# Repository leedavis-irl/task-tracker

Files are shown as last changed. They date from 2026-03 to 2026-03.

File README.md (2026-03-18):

# Task Tracker

A physical IoT chore tracking system built with ESP32 buttons, a Flask server, and an e-ink display. Buttons are placed at task locations around the house. When a task is completed, pressing the button records it on a central server. A wall-mounted e-ink display shows a live checklist, and a daily summary is sent via Signal.

## How It Works

```
Button press (WiFi) ──HTTP POST──→ Flask server (EC2) ←──HTTP GET── E-ink display (WiFi)
                                        │
                                   9:30 AM daily
                                        │
                                   Signal relay ──→ Signal group
```

1. **Buttons** — Seeed XIAO ESP32-C6 boards with a tact switch, passive buzzer, and LiPo battery. Flashed with ESPHome. On press, sends an HTTP POST to the server with `{"owner": "...", "task": "..."}`.
2. **Server** — Flask app on EC2. Accepts button presses during a configurable morning window (default 6:00–9:30 AM). Tracks task completion per person per day. Resets at 3:00 AM.
3. **Display** — Waveshare 7.5" e-ink (800×480 B/W) on an ESP32 driver board. Polls the server every 60 seconds and renders a two-column checklist.
4. **Signal relay** — Separate Flask endpoint on the same server. At 9:30 AM, the server sends a summary message to a Signal group via signal-cli.

### Buzzer Feedback

Buttons give audio feedback on press:
- **Two short clicks** — task recorded successfully
- **One long click** — task was already completed today
- **Three quick clicks** — outside the active window or error

## Hardware

| Component | Spec | Qty |
|---|---|-----|
| Seeed XIAO ESP32-C6 | WiFi microcontroller, USB-C, LiPo charging | 1 per button |
| 6mm tact switch | Momentary, through-hole | 1 per button |
| Passive buzzer | ~12mm, driven via GPIO toggle | 1 per button |
| 400mAh LiPo | 3.7V, soldered to BAT+/BAT- pads | 1 per button |
| Waveshare 7.5" V2 e-ink | 800×480 B/W, SPI interface | 1 |
| ESP32 driver board | Waveshare universal e-Paper driver, Rev 3 | 1 |
| 3.7V LiPo | Powers display via 5V/GND pins | 1 |

Full bill of materials with sourcing links in `docs/05-bill-of-materials.md`.

### 3D-Printed Enclosures

Button enclosures are designed in OpenSCAD (`3d/button-enclosure.scad`):
- Two-piece snap-fit design (base + lid with integrated button cap)
- Internal layout: battery, tact switch on pillar mount, XIAO, buzzer
- USB-C access on bottom edge for charging
- Buzzer sound holes on side wall

## Server

### Endpoints

| Method | Path | Description |
|---|---|---|
| `GET` | `/health` | Health check — returns `{"status": "ok", "date": "YYYY-MM-DD"}` |
| `POST` | `/press` | Record task completion — body: `{"owner": "...", "task": "..."}` |
| `GET` | `/state` | Current state as flat JSON (for display polling) |

### Response Codes for `/press`

| Status | Meaning |
|---|---|
| `ok` | Task recorded |
| `already_done` | Task was already completed today |
| `outside_window` | Not within the active time window |
| `not_today` | Task not applicable today (day-specific scheduling) |
| `invalid` | Unknown owner or task |

### Task Definitions

Tasks are defined in `server.py` as Python dicts:

```python
DAILY_TASKS = {
    "child_a": ["laundry", "teeth", "plates", "pills"],
    "child_b": ["laundry", "teeth", "plates"],
}
```

Day-specific tasks (e.g., Wednesday-only) are supported via separate dicts.

### Scheduled Jobs

- **3:00 AM Pacific** — Reset all task state for the new day
- **9:30 AM Pacific** — Send Signal summary (e.g., "Child A done | Child B missed: teeth, plates")

## ESPHome Configuration

Devices use a base template pattern:

```
esphome/
├── .base-common.yaml      WiFi, API, OTA (shared by all devices)
├── .base-button.yaml       Button logic, HTTP POST, buzzer, deep sleep
├── .base-display.yaml      SPI, polling, rendering
├── button-*.yaml           Per-device configs (just substitutions + package includes)
├── display-front-door.yaml Full display config with rendering lambda
└── secrets.yaml.template   Template for WiFi/API credentials
```

Each button config is ~10 lines of substitutions that reference the base templates.

### GPIO Assignments (Buttons)

| Pin | Function |
|-----|---|
| GPIO1 (D1) | Tact switch input (active LOW, internal pullup) |
| GPIO2 (D2) | Passive buzzer output (GPIO toggle) |
| GPIO15 | Onboard LED status |
| BAT+/BAT- | LiPo battery pads |

### Known Platform Issues

- **LEDC/rtttl** does not work on ESP32-C6 with esp-idf framework — buzzer uses plain GPIO toggle
- **Deep sleep** disabled due to ESP-IDF 5.1.5 crash on ESP32-C6 wake
- **`verify_ssl: false`** required in HTTP requests even for plain HTTP on esp-idf, or requests fail silently

## Deployment

### Server Setup

```bash
# On EC2
pip install -r server/requirements.txt
cp .env.example .env    # Edit with your values

# Run directly
python server/server.py

# Or via systemd (see server/task-tracker.service)
sudo systemctl enable task-tracker
sudo systemctl start task-tracker
```

### Signal Relay

```bash
# Same EC2 instance, separate service
pip install flask
python ec2/signal_relay.py

# Requires signal-cli installed and registered
```

### Flashing Devices

```bash
# First flash (USB)
esphome run esphome/button-child_a-laundry.yaml

# Subsequent updates (OTA)
esphome run esphome/button-child_a-laundry.yaml --device 192.168.x.x
```

Copy `esphome/secrets.yaml.template` to `esphome/secrets.yaml` and fill in WiFi credentials and server IP before flashing.

## Documentation

Detailed guides in `docs/`:

| Doc | Contents |
|-----|---|
| `01-architecture.md` | System design, data flow, component responsibilities |
| `02-technical-best-practices.md` | ESPHome patterns, server config, e-ink gotchas |
| `03-project-process.md` | Development workflow, testing, deployment procedures |
| `04-task-template.md` | Step-by-step guide for adding new tasks |
| `05-bill-of-materials.md` | Parts list, sourcing, cost breakdown |
| `06-button-design-spec.md` | Enclosure design, mechanical specs |
| `07-deployment.md` | Full EC2 setup and device commissioning |
| `08-button-build-guide.md` | Complete soldering and assembly walkthrough |

## Tech Stack

- **Firmware:** ESPHome (ESP-IDF framework)
- **Microcontrollers:** Seeed XIAO ESP32-C6
- **Display:** Waveshare 7.5" V2 e-ink
- **Server:** Python, Flask, APScheduler
- **Messaging:** signal-cli
- **Enclosures:** OpenSCAD, 3D printed (PLA/PETG)

## License

Private project. Not licensed for redistribution.

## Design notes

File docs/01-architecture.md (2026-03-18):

# Task Tracker System Architecture

## System Overview

A multi-child chore completion tracker using physical IoT buttons, a centralized e-ink status display, and Signal notifications. Designed for Ryker and Logan, expandable to additional children and tasks.

## Core Design Principles

**Physical-first interaction.** Kids press a real button when they complete a task. No apps, no screens to unlock, no accounts to manage. The button is the interface.

**Passive visibility.** The e-ink display at the front door shows current status without power draw, without screens lighting up, without anyone needing to check anything. You see it when you walk past.

**Notification where people look.** Signal was chosen over Slack because more household members check Signal. Technical elegance loses to actual eyeballs.

**One task = one button per child.** Shared tasks (laundry, teeth, plates) get separate buttons with stickers for each kid. No press-counting, no NFC tags, no conventions a 7-year-old has to remember at 7am.

## Hardware Inventory

| Device | Qty | Role | Location |
|---|---|---|---|
| Seeed XIAO ESP32-C6 IoT Button | 2 | Laundry (Ryker + Logan) | Hall laundry chute |
| Seeed XIAO ESP32-C6 IoT Button | 2 | Teeth (Ryker + Logan) | Bathroom |
| Seeed XIAO ESP32-C6 IoT Button | 2 | Plates (Ryker + Logan) | Kitchen sink area |
| Seeed XIAO ESP32-C6 IoT Button | 1 | AM Pills (Ryker only) | Pill case |
| ESP32 dev board + Waveshare 7.5" e-ink | 1 | Status display | Front door |

**Total: 8 devices, ~$110-120**

## Data Flow

```
┌─────────────┐     HTTP POST /press     ┌───────────────────┐
│  IoT Button  │────────────────────────▶│  Flask Server      │
│  (ESP32-C6)  │                         │  (EC2, port 8765)  │
└─────────────┘                          └────────┬──────────┘
                                                   │
                                         ┌─────────┴─────────┐
                                         │                     │
                              GET /state │                     │ 9:30 AM summary
                                         ▼                     ▼
                                  ┌─────────────┐    ┌──────────────┐
                                  │  E-Ink       │    │  Signal Relay │
                                  │  Display     │    │  (EC2 :8766)  │
                                  │  (ESPHome)   │    └──────┬───────┘
                                  └─────────────┘           │
                                                             ▼
                                                    ┌──────────────┐
                                                    │  Signal      │
                                                    │  → Favalon   │
                                                    └──────────────┘
```

### Step-by-step flow for a single button press:

1. **Button press** → ESP32-C6 wakes from deep sleep
2. **ESPHome firmware** → Connects to WiFi, sends HTTP POST to Flask server with `{"owner": "ryker", "task": "teeth"}`
3. **Flask server checks** → Is the active window open (6:00–9:30 AM)? Is this task already done?
4. **Server updates state** → Marks task as done in `state.json`, returns `{"status": "ok"}`
5. **Button buzzer feedback** → Two clicks (success), one long click (already done), three quick clicks (outside window / error)
6. **Display polls** → Every 60 seconds, the e-ink display GETs `/state` from the server
7. **E-ink refreshes** → Redraws two-column checklist with updated checkmarks

### Daily reset flow:

1. **APScheduler job** → Fires at 3:00 AM Pacific
2. **Reset all states** → `state.json` wiped and rebuilt with today's tasks
3. **Display polls** → Picks up fresh state on next 60-second cycle

### 9:30 AM Signal summary:

1. **APScheduler job** → Fires at 9:30 AM Pacific
2. **Build summary** → Checks which tasks each child completed/missed
3. **POST to Signal relay** → Sends message to EC2 Signal relay on port 8766
4. **Signal delivery** → `signal-cli` sends message to Favalon group

## Component Responsibilities

### ESPHome (runs on all 8 devices)

**On buttons:**
- Deep sleep management (wake on button press)
- WiFi connection
- HTTP POST to Flask server with owner/task payload
- Buzzer feedback based on server response (success / already done / outside window)
- Battery voltage reporting (if battery-powered)

**On display:**
- Polls Flask server every 60 seconds via HTTP GET `/state`
- Parses flat JSON response into boolean globals
- Renders two-column layout via display lambda
- Three display modes: outside window, active checklist, all-done celebration

### Flask Server (runs on EC2)

- **Task registry** → Defines all tasks and owners in Python (DAILY_TASKS)
- **State machine** → Tracks completion status per child per task per day in `state.json`
- **Active window** → Only accepts button presses between 6:00–9:30 AM Pacific
- **API endpoints** → `/press` (POST), `/state` (GET), `/health` (GET)
- **Daily reset** → APScheduler clears all states at 3:00 AM Pacific
- **Signal summary** → APScheduler sends one summary at 9:30 AM Pacific via EC2 relay

### Signal Relay (runs on EC2, port 8766)

- Receives summary message from Flask server via HTTP POST
- Sends to Favalon Signal group via `signal-cli`
- Authenticated with shared `RELAY_TOKEN` header

## Server State Model

State is stored in `state.json` on disk. The `/state` endpoint returns a flat JSON object for the display:

```json
{
  "active_window": true,
  "both_done": false,
  "ryker_laundry": false,
  "ryker_teeth": true,
  "ryker_plates": false,
  "ryker_pills": false,
  "ryker_done": false,
  "logan_laundry": false,
  "logan_teeth": false,
  "logan_plates": false,
  "logan_done": false
}
```

## Network Topology

```
Internet
├── EC2 (34.208.73.189)
│   ├── Flask task-tracker server (:8765) — systemd service
│   └── Signal relay (:8766) — signal-cli
│
WiFi Network (Avalon)
├── 7× Seeed XIAO ESP32-C6 buttons (HTTP POST to EC2)
└── 1× ESP32 + e-ink display (HTTP GET from EC2, polls every 60s)
```

All button and display devices communicate with the EC2 server over the internet via HTTP. No local server required. No Home Assistant involvement.

## Expansion Points

**New task:** Add button hardware + ESPHome config + update `DAILY_TASKS` (or `WEDNESDAY_TASKS` for day-specific tasks, currently empty) in `server.py` + update display lambda. Follow the task template in `04-task-template.md`.

**New child:** Add stickered buttons for shared tasks + child-specific buttons. Add new owner to server task definitions. Update display lambda for additional column (display supports up to 3-4 columns at 7.5").

**New notification channel:** Modify `job_morning_summary()` in `server.py` to send via additional channels.

**Schedule changes:** Modify task definitions in `server.py`. The `tasks_for_today()` function makes day-of-week logic trivial to adjust.

## Key Technical Decisions

| Decision | Choice | Rationale |
|---|---|---|
| Server location | AWS EC2 | Always-on, no dependency on local hardware being awake |
| Communication | HTTP (not ESPHome native API) | Buttons POST directly to server; no HA intermediary needed |
| State storage | JSON file on disk | Simple, inspectable, survives restarts |
| Display update | Polling (60s interval) | Simpler than push; e-ink refresh rate makes real-time unnecessary |
| Display tech | E-ink via ESPHome | Always visible unpowered, wall-mounts cleanly |
| Notification | Signal via signal-cli on EC2 | Household actually checks Signal; one summary per day, not per-task |
| Button hardware | Seeed XIAO ESP32-C6 | $10/ea, deep sleep support, ESPHome compatible |
| Config management | ESPHome packages | DRY configs, base templates + per-device overrides |
| Timezone handling | `zoneinfo` Pacific | Server runs on UTC EC2 but all logic uses America/Los_Angeles |

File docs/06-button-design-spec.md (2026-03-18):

# Button Unit Design Specification

Last updated: 2026-02-26

## Design Philosophy

Each button is a standalone wall-mounted unit placed at the location where a task is completed (toothbrush button in the bathroom, dishes button by the sink, etc.). The button press itself should be the reward — a big satisfying palm-slap with an audible confirmation sound that makes boring routines feel like an event.

## Form Factor

### Plunger / Hit Target
- **Diameter**: ~55mm (full palm slap, not finger poke)
- **Shape**: Dome or mushroom cap — convex top surface that invites hitting
- **Travel**: 3-5mm of vertical plunger movement before bottoming out on tact switch
- **Spring-back**: Printed living hinge or captive flexure arms return plunger to resting position after press
- **Surface**: Per-task icon embossed or recessed into top face (see Visual Identity below)
- **Feel**: Solid *thonk* at bottom of travel, immediate snap-back

### Enclosure / Base
- **Shape**: Round or rounded-square base that matches plunger aesthetic
- **Diameter/width**: ~65-70mm (provides rim around plunger)
- **Depth**: ~20-25mm (houses all electronics)
- **Wall mount**: Flat back with Command strip recess or keyhole slot
- **USB-C access**: Port opening on bottom edge for charging/flashing (gravity keeps dust out)
- **Sound**: Open slot or grille for buzzer audio to escape enclosure

### Internal Layout (top to bottom)
```
[Plunger cap — 55mm dome, 3-5mm travel]
        ↓ (presses down on)
[Tact switch — 6×6×5mm, mounted on internal post]
[Buzzer — 12mm passive piezo, mounted to side wall]
[XIAO ESP32-C6 — 21×17.8mm, USB-C port aligned to enclosure opening]
[LiPo battery — 5×20×35mm, below or beside XIAO]
```

## Mechanical Design

### Plunger Mechanism
The plunger is a separate printed piece that moves vertically inside the base. It does NOT click on its own — all tactile feedback comes from the real tact switch at the bottom of travel.

**Travel amplification**: The tact switch has only ~0.25mm of its own travel. The plunger adds 3-5mm of free travel before contact, creating anticipation, then the switch click provides the payoff at the bottom.

**Return mechanism options** (choose during prototyping):
1. **Living hinge arms** (simplest): 2-4 thin PLA/PETG flexure arms connecting plunger to base, pre-loaded to push plunger up. Risk: fatigue over thousands of cycles.
2. **Captive silicone o-ring**: Plunger slides on a central post, compressed o-ring provides return force. More durable, slightly more complex assembly.
3. **Printed leaf springs**: Angled tabs that flex and return. Good middle ground.

**Plunger guides**: Central post or rail system prevents wobble and keeps press straight regardless of where on the dome the kid's hand lands.

### Tact Switch Mounting
- Switch sits on a raised printed post at the bottom of the plunger cavity
- Post height calibrated so switch actuates at the bottom of plunger travel
- Two wires (GPIO + GND) route from switch down to XIAO

### Durability
- Target: 10,000+ presses minimum (roughly 3+ years of daily use)
- PETG preferred over PLA for the plunger and return mechanism (better fatigue resistance)
- PLA acceptable for the base enclosure

## Audio Feedback

### Hardware
- Passive piezo buzzer (~12mm), 2 pins soldered to XIAO GPIO + GND
- Mounted inside enclosure with sound slot/grille in wall for audio escape

### Behavior (configured in ESPHome)
- **On press**: Immediate confirmation tone (short beep or custom sound)
- **Possible enhancements** (implement after MVP):
  - Different tone per task (brush teeth = high sparkle, take out trash = low bonk)
  - Ascending pitch as kid completes more tasks in the morning
  - Victory jingle when all tasks complete
  - Sad trombone if pressed after deadline (just kidding... maybe)

### ESPHome Config Pattern

> **LEDC/rtttl does NOT work** on ESP32-C6 with esp-idf framework (outputs 0V). Use plain GPIO toggle instead — produces audible clicks on the passive buzzer.

```yaml
output:
  - platform: gpio
    pin: GPIO2    # D2 on XIAO ESP32-C6
    id: buzzer_out

# Feedback via GPIO toggle patterns (on/off with delays):
# - Two clicks = success
# - One long click = already done
# - Three quick clicks = outside window / error
```

## Visual Identity

### Per-Task Icons
Each button has an icon embossed or recessed into the plunger face so kids (and adults) can instantly identify the task. Icons designed in OpenSCAD as 2D profiles extruded into the dome surface.

Candidate icons (finalize with kids):
| Task | Icon Idea |
|---|---|
| Brush teeth | Toothbrush or tooth |
| Get dressed | T-shirt or hanger |
| Make bed | Bed or pillow |
| Put away dishes | Plate + fork |
| Dirty clothes in hamper | Laundry basket |
| Backpack ready | Backpack |
| Wednesday: Take out trash | Trash can |
| Wednesday: Extra chore TBD | TBD |

### Color Coding
Since buttons are placed at task locations (not grouped by kid), and both kids do the same tasks, there are two approaches:

**Option A: Shared buttons** — one button per task location, either kid can press it, system tracks who via server logic (e.g., alternating presses, or a "who are you" toggle). Fewer buttons, simpler install.

**Option B: Paired buttons** — two buttons per task location, one per kid, different colors. More buttons (18 instead of 9), but zero ambiguity. Color per kid (e.g., Ryker = blue, Logan = green).

**Recommendation**: Start with Option B (paired). It's more hardware but eliminates all "whose turn" confusion. 18 buttons = 18 XIAO boards... except we only have 9. So either:
- Option A with shared buttons (9 boards, need identification mechanism)
- Option B with 9 boards covering one kid, expand later
- Revisit architecture

> **DECISION NEEDED**: Shared vs paired buttons. This affects board count and enclosure design.

## Mounting

### Location Strategy
Buttons mounted as close to task completion point as possible:
- Bathroom wall (brush teeth)
- Near laundry hamper/chute (dirty clothes)
- Near kitchen sink (dishes)
- Bedroom wall (make bed, get dressed)
- Near front door (backpack)
- Near trash/recycling (Wednesday tasks)

### Attachment
- **Primary**: Command strips (3M damage-free, removable, re-positionable)
- **Backup**: Small screws into wall if Command strips don't hold
- Flat back surface with recessed area for Command strip adhesive
- Button should be at kid-reachable height (~36-42" from floor depending on kid)

## Charging

- USB-C port accessible on bottom edge of enclosure
- Plug in any USB-C cable to charge (XIAO onboard charger handles LiPo)
- Charging frequency: estimated every few months (15µA deep sleep + brief wake per press)
- No indicator LED needed — XIAO has onboard charge LED visible through enclosure gap or translucent section

## GPIO Allocation (XIAO ESP32-C6)

| GPIO | XIAO Pin | Function |
|---|---|---|
| GPIO1 | D1 | Tact switch input (internal pull-up, active LOW) |
| GPIO2 | D2 | Passive buzzer output (plain GPIO toggle) |
| GPIO15 | (onboard) | Status LED (active low) |
| BAT+ | pad near D5 | LiPo positive |
| BAT- | pad near D8 | LiPo negative |
| USB-C | — | Charging + flashing |

> **Pin mapping**: D0=GPIO0, D1=GPIO1, D2=GPIO2, D3=GPIO21, D4=GPIO22, D5=GPIO23. GPIO3 is RF switch power (board-internal, do NOT use).

## Prototype Plan

1. **Mechanical prototype first**: Print plunger + base without electronics. Test travel feel, spring-back, palm-slap satisfaction.
2. **Electronics test**: Solder one complete unit (XIAO + battery + switch + buzzer). Confirm ESPHome config, deep sleep wake, buzzer tones.
3. **Integrated prototype**: Combine mechanical + electronics in one unit. Wall-mount test.
4. **Iterate**: Refine based on kid feedback before building all 9.

## Open Questions

- [ ] Shared vs paired buttons (see Visual Identity section)
- [ ] Specific plunger return mechanism (living hinge vs o-ring vs leaf spring) — decide during prototyping
- [ ] Icon designs — involve kids in choosing
- [x] ~~Exact GPIO pin assignments for switch and buzzer~~ — resolved: D1/GPIO1 (switch), D2/GPIO2 (buzzer)
- [ ] PETG color filament availability for kid-specific colors

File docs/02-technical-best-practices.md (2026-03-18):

# Technical Best Practices

## ESPHome Configuration

### File Organization

Use ESPHome's packages system to keep configs DRY. The structure:

```
esphome/
├── secrets.yaml                    # WiFi, API keys, server IP
├── .base-common.yaml               # WiFi, API, OTA, logger (all devices)
├── .base-button.yaml               # Button-specific: HTTP POST, buzzer feedback
├── .base-display.yaml              # Display-specific: SPI, fonts, polling base
├── button-ryker-laundry.yaml       # Per-device config
├── button-ryker-teeth.yaml
├── button-logan-laundry.yaml
├── ...
└── display-front-door.yaml
```

Dot-prefix on base files (`.base-*`) keeps them grouped at top of directory listings and signals "don't flash this directly."

### Base Common Config (.base-common.yaml)

Every device inherits this. Contains:

```yaml
wifi:
  ssid: !secret wifi_ssid
  password: !secret wifi_password
  ap:
    ssid: "${device_name} Fallback"
    password: "fallback1234"

api:
  encryption:
    key: !secret api_encryption_key

ota:
  - platform: esphome
    password: !secret ota_password

logger:
  level: INFO
```

### Per-Device Config Pattern

Each device YAML is minimal — just substitutions and package includes:

```yaml
substitutions:
  device_name: button-ryker-laundry
  owner: ryker
  task: laundry
  pi_ip: !secret pi_ip

packages:
  common: !include .base-common.yaml
  button: !include .base-button.yaml
```

This means adding a new button = copying a 10-line file and changing 4 substitution values.

### Substitutions as the Interface

Substitutions are the contract between base configs and per-device configs:

| Substitution | Used In | Example |
|---|---|---|
| `${device_name}` | Common (hostname, AP name) | `button-ryker-laundry` |
| `${owner}` | Button base (HTTP POST body) | `ryker` |
| `${task}` | Button base (HTTP POST body) | `laundry` |
| `${pi_ip}` | Button/display base (server URL) | `34.208.73.189` |

### Naming Conventions (ESPHome)

**Device names:** `{type}-{owner}-{task}` using hyphens (RFC1912 compliant)
- `button-ryker-laundry`
- `button-logan-teeth`
- `display-front-door`

### Deep Sleep for Buttons

Buttons spend 99.9% of their time asleep. Config pattern:

```yaml
deep_sleep:
  id: deep_sleep_control
  run_duration: 10s        # Max awake time per press
  sleep_duration: 0s       # Sleep indefinitely (wake on pin)
  wakeup_pin:
    number: GPIO1
    mode: INPUT_PULLUP
    inverted: true
```

Key rules:
- **10 second max awake time** — connect WiFi, send HTTP POST, get response, sleep
- **No periodic wake** — only wake on physical button press
- **Fallback** — if WiFi fails within 10s, sleep anyway (don't drain battery)

> **Note:** Deep sleep is currently disabled due to ESP-IDF 5.1.5 sleep crash on ESP32-C6. Will be re-enabled in a future firmware update.

### Buzzer Feedback Pattern

```yaml
output:
  - platform: gpio
    pin: GPIO2    # D2 on XIAO ESP32-C6
    id: buzzer_out

# Feedback via GPIO toggle patterns (on/off with delays):
# - Two clicks = success ("ok" from server)
# - One long click = already done today
# - Three quick clicks = outside window / error
```

> **LEDC/rtttl does NOT work** on ESP32-C6 with esp-idf framework (outputs 0V). Use plain GPIO toggle instead.

### HTTP Request Configuration

Both buttons and display use the `http_request` component. Critical setting:

```yaml
http_request:
  useragent: "ESPHome Task Button"
  timeout: 5s
  verify_ssl: false    # Required — without this, HTTP requests fail silently on esp-idf
```

The `verify_ssl: false` is needed even for plain HTTP on the esp-idf framework. Without it, requests will silently fail with no error in logs.

### E-Ink Display Best Practices

**Pin configuration for Waveshare 7.5" V2 with ESP32 driver board:**

```yaml
spi:
  clk_pin: GPIO13
  mosi_pin: GPIO14

display:
  - platform: waveshare_epaper
    id: eink_display
    model: 7.50inV2
    cs_pin: GPIO15
    dc_pin: GPIO27
    busy_pin:
      number: GPIO25
      inverted: true      # REQUIRED for 7.50in V2 — prevents display damage
    reset_pin: GPIO26
    update_interval: never  # Only update after receiving new state from server
    lambda: |-
      // Display rendering code here
```

**Critical rules:**
- `busy_pin: inverted: true` is MANDATORY for 7.50in V2 models. Omitting this can damage the display.
- Set `update_interval: never` — the poll script calls `epaper.update()` after receiving new state
- Keep fonts to 2-3 sizes max to conserve flash memory
- Use ASCII glyphs only ([X], ( ), -) — Unicode markers (✓, ○, ⚠) require special font files
- Restrict glyph sets to only the characters actually used to minimize flash usage

### Secrets Management

Single `secrets.yaml` in the ESPHome config directory:

```yaml
wifi_ssid: "YourNetworkName"
wifi_password: "YourWiFiPassword"
api_encryption_key: "base64-encoded-32-byte-key"
ota_password: "OtaUpdatePassword"
pi_ip: "34.208.73.189"
relay_token: "your_shared_secret"
```

**Rules:**
- Never commit secrets.yaml to version control
- Generate API encryption key with: `python3 -c "import secrets, base64; print(base64.b64encode(secrets.token_bytes(32)).decode())"`
- All devices share the same API key
- OTA password is separate from API key
- `pi_ip` is the EC2 server address (misnamed for historical reasons — it's not a Pi)

## Server Configuration

### Task Definitions

Tasks are defined in `server.py` as Python dicts:

```python
DAILY_TASKS = {
    "ryker": ["laundry", "teeth", "plates", "pills"],
    "logan": ["laundry", "teeth", "plates"],
}

WEDNESDAY_TASKS = {
    "ryker": [],
    "logan": [],
}
```

To add a new task, add it to the appropriate dict and restart the server.

### Timezone Handling

The server runs on EC2 (UTC system clock) but all time-dependent logic uses Pacific time:

```python
from zoneinfo import ZoneInfo
PACIFIC = ZoneInfo("America/Los_Angeles")

# All datetime.now() calls use:
now = datetime.now(PACIFIC)
```

This applies to: active window check, weekday calculation for day-specific tasks, and daily reset scheduling (APScheduler uses `timezone="America/Los_Angeles"`).

### Signal Integration

Signal messages are sent via a relay endpoint on EC2 (port 8766) using `signal-cli`. The task tracker server sends one summary per day at 9:30 AM Pacific:

```
Ryker done | Logan missed: teeth, plates
```

The relay authenticates via `X-Relay-Token` header (shared secret between task tracker server and signal relay).

## Version Control

### What to track in Git

```
task-tracker/
├── esphome/
│   ├── .base-common.yaml
│   ├── .base-button.yaml
│   ├── .base-display.yaml
│   ├── button-*.yaml           (one per physical button)
│   └── display-front-door.yaml
├── server/
│   ├── server.py
│   ├── requirements.txt
│   └── task-tracker.service
├── ec2/
│   └── signal_relay.py
├── docs/
│   └── *.md
└── .gitignore
```

### .gitignore

```
secrets.yaml
.esphome/
buzzer-test.yaml
*-flash.yaml
*.pyc
```

### Commit Conventions

- `feat(button): add Ryker vitamins daily button`
- `fix(display): correct column alignment for two-child layout`
- `docs: update task template with schedule configuration notes`
- `refactor(esphome): extract LED feedback to shared package`

## Error Handling

### Button fails to connect to WiFi
ESPHome's 10-second run_duration ensures the button goes back to sleep. Battery is preserved. Task simply doesn't register — kid can press again.

### Display stops updating
E-ink retains last image. Stale data is visible and obvious (yesterday's tasks still shown). Check EC2 server is running: `systemctl status task-tracker`.

### Server goes down
Buttons will get HTTP errors and play the three-click error pattern. Display retains last rendered image. Restart with `sudo systemctl restart task-tracker` on EC2.

### Signal relay fails
Summary message fails silently. Tasks still register on the server and display. Signal is a nice-to-have, not a critical path.

### Duplicate button press
Server checks if task is already done and returns `"already_done"`. Button plays one long click. State is not modified.

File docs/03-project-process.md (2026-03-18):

# Project Process

## Development Phases

### Phase 1: Infrastructure (do once)

1. **Set up ESPHome environment** on local machine (`pip install esphome`)
2. **Create base YAML files** (`.base-common.yaml`, `.base-button.yaml`, `.base-display.yaml`)
3. **Create `secrets.yaml`** with WiFi credentials, API keys, server IP
4. **Deploy Flask server** to EC2 with systemd service
5. **Deploy Signal relay** to EC2 with signal-cli
6. **Set up Git repo** with initial commit of all config files

### Phase 2: First Button (prove the pattern)

Build ONE complete task end-to-end before replicating. Suggested: **Ryker teeth button**.

1. Flash ESPHome to one Seeed XIAO ESP32-C6 via USB
2. Verify WiFi connects and button boots cleanly (two clicks)
3. Press button, verify HTTP POST reaches EC2 server
4. Verify server records the task (`/state` shows `true`)
5. Verify display picks up the change on next poll
6. Test daily reset clears state
7. Test duplicate press protection (one long click)

**Do not proceed to Phase 3 until this single button works completely.**

### Phase 3: Fleet Deployment (replicate the pattern)

For each remaining button:
1. Copy per-device YAML, change substitutions
2. Flash ESPHome firmware via USB
3. Verify WiFi connection and boot feedback
4. Test button → server → display chain
5. Apply sticker, mount with Command strip

### Phase 4: Polish

1. Finalize display layout (both columns, all tasks)
2. Test full day cycle: morning tasks → display updates → 9:30 AM summary → reset overnight
3. Verify day-specific tasks (if any) appear/hide correctly
4. Document any deviations from best practices

## Development Workflow (per-session)

### Before starting work

1. Pull latest from Git
2. Verify EC2 server is running: `curl http://34.208.73.189:8765/health`
3. Check server logs if needed: `ssh ubuntu@34.208.73.189 "sudo journalctl -u task-tracker --since '1 hour ago'"`

### Making changes

1. **ESPHome changes:** Edit YAML → compile (`esphome compile`) → flash OTA or USB (`esphome upload`)
2. **Server changes:** Edit `server.py` → deploy to EC2 → restart service (`sudo systemctl restart task-tracker`)
3. **Task definition changes:** Edit `DAILY_TASKS` (or `WEDNESDAY_TASKS` for day-specific tasks) in `server.py` → restart server → update display lambda if new task row needed

### After making changes

1. Test the specific change manually (press button, check state, check display)
2. Commit to Git with descriptive message
3. Note any issues in project log

## Testing Checklist

### Per-button commissioning test

Run this for every new button before mounting:

- [ ] ESPHome firmware compiles without errors
- [ ] Device connects to WiFi (check serial logs)
- [ ] Boot feedback: two clicks heard
- [ ] Button press: HTTP POST reaches EC2 server (check server logs)
- [ ] Server responds `"ok"` and task state updates
- [ ] Display shows updated state on next poll
- [ ] Second button press returns `"already_done"` (one long click)
- [ ] Device returns to deep sleep after press (when deep sleep is re-enabled)

### System-level tests (run after fleet changes)

- [ ] Daily reset clears all states at 3 AM (test by temporarily changing reset time)
- [ ] Display shows correct day's tasks (including any day-specific tasks if configured)
- [ ] 9:30 AM Signal summary sends correctly
- [ ] Display handles all tasks checked off (celebration screen)
- [ ] Display handles zero tasks checked off (morning state)

### Edge case tests

- [ ] Button press while WiFi is down → button sleeps, no crash
- [ ] Button press while server is down → three clicks (error), no crash
- [ ] Multiple buttons pressed simultaneously → all register correctly
- [ ] Press day-specific task button on wrong day → server returns `"not_today"`, three clicks
- [ ] Press outside 6–9:30 AM window → server returns `"outside_window"`, three clicks

## Deployment Steps (mounting a button)

1. **Label the button** with kid's sticker and task icon/text
2. **Test one more time** in the mounting location (WiFi signal check)
3. **Clean surface** with isopropyl alcohol
4. **Apply Command strip** to button back
5. **Press to wall** for 30 seconds
6. **Verify press from mounted position** — check EC2 server logs to confirm POST received
7. **Take a photo** of mounted button for documentation
8. **Update inventory** in architecture doc if placement changed

## Rollback Procedures

### Bad ESPHome firmware flash

ESPHome devices have fallback AP mode. If a bad flash prevents WiFi connection:
1. Look for `{device_name} Fallback` WiFi network
2. Connect and navigate to `192.168.4.1`
3. Flash corrected firmware via web interface

### Server issues

```bash
# SSH into EC2
ssh -i ~/.ssh/the-pem-key.pem ubuntu@34.208.73.189

# Check status
sudo systemctl status task-tracker

# View logs
sudo journalctl -u task-tracker -f

# Restart
sudo systemctl restart task-tracker
```

### Signal relay issues

```bash
# On EC2:
sudo systemctl status signal-relay
sudo systemctl restart signal-relay
```

## Monitoring

### Daily glance checks

- Server health: `curl http://34.208.73.189:8765/health`
- Current state: `curl http://34.208.73.189:8765/state | python3 -m json.tool`
- Signal group: confirm 9:30 AM summary arrived

### Weekly maintenance

- Check button batteries if not USB-powered
- Review EC2 server logs for recurring warnings
- Verify display is rendering cleanly (e-ink ghosting check)
- Git commit any uncommitted changes

### Monthly review

- Are kids actually using it? Talk to them.
- Any tasks need adding/removing/changing?
- Any buttons fallen off walls? (Command strip refresh)
- Update ESPHome if updates available

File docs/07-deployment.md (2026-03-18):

# Task Tracker — Deployment Guide

End-to-end setup for the Avalon household task tracker:
7 ESPHome buttons + 1 e-ink display + EC2 server + EC2 Signal relay.

---

## Overview

```
[Button press]
     │  HTTP POST /press
     ▼
[EC2 Server :8765]  ──── GET /state ────▶  [E-ink Display]
     │
     │  9:30 AM summary only
     ▼
[EC2 :8766 /send-signal]
     │
     ▼
[Signal → Favalon group]
```

**Signal behavior:** One message per day, sent at 9:30 AM Pacific.
Format: `Ryker done | Logan missed: teeth, plates`
No real-time notifications when tasks are completed.

---

## Prerequisites

- AWS EC2 instance (currently at 34.208.73.189) with ports 8765 and 8766 open
- SSH key: `~/.ssh/the-pem-key.pem`
- signal-cli configured on EC2 for +17074748930
- 7× Seeed XIAO ESP32-C6 boards
- 1× Waveshare 7.5" V2 e-ink display + Waveshare ESP32 driver board
- A machine with ESPHome installed (`pip install esphome`)

---

## Part 1 — EC2 Signal Relay

Do this first so you can test it independently.

### 1.1 SSH into EC2

```bash
ssh -i ~/.ssh/the-pem-key.pem ubuntu@34.208.73.189
```

### 1.2 Copy signal_relay.py

```bash
scp -i ~/.ssh/the-pem-key.pem \
  task-tracker/ec2/signal_relay.py \
  ubuntu@34.208.73.189:~/signal_relay.py
```

### 1.3 Install Flask (if not already present)

```bash
pip3 install flask
```

### 1.4 Choose a relay token

Pick any strong random string. You'll use the same value in two places:
- `RELAY_TOKEN` env var on EC2 (signal relay)
- `RELAY_TOKEN` env var in the task-tracker systemd service

```bash
# Generate one:
openssl rand -hex 24
```

### 1.5 Run standalone (test first)

```bash
RELAY_TOKEN=your_token_here python3 ~/signal_relay.py &
```

### 1.6 Open firewall port 8766

In AWS Console → EC2 → Security Groups, add inbound rule:
- Type: Custom TCP
- Port: 8766
- Source: 0.0.0.0/0 (or restrict to your home IP)

### 1.7 Test it

```bash
curl -X POST http://34.208.73.189:8766/send-signal \
  -H "Content-Type: application/json" \
  -H "X-Relay-Token: your_token_here" \
  -d '{"message": "Test from task tracker"}'
# Expected: {"status": "sent"}
```

Check that the message appeared in the Favalon Signal group.

### 1.8 Make it persistent (systemd)

```bash
sudo cat > /etc/systemd/system/signal-relay.service << 'EOF'
[Unit]
Description=Signal Relay for Task Tracker
After=network.target

[Service]
Type=simple
User=ubuntu
Environment="RELAY_TOKEN=REPLACE_WITH_YOUR_TOKEN"
ExecStart=/usr/bin/python3 /home/ubuntu/signal_relay.py
Restart=always
RestartSec=5

[Install]
WantedBy=multi-user.target
EOF

sudo systemctl daemon-reload
sudo systemctl enable signal-relay
sudo systemctl start signal-relay
sudo systemctl status signal-relay
```

---

## Part 2 — EC2 Task Tracker Server

### 2.1 Copy server files to EC2

```bash
scp -i ~/.ssh/the-pem-key.pem \
  task-tracker/server/server.py \
  task-tracker/server/requirements.txt \
  ubuntu@34.208.73.189:~/task-tracker/
```

### 2.2 Set up Python virtualenv

```bash
ssh -i ~/.ssh/the-pem-key.pem ubuntu@34.208.73.189

cd ~/task-tracker
python3 -m venv venv
source venv/bin/activate
pip install -r requirements.txt
deactivate
```

### 2.3 Configure the systemd service

```bash
sudo cat > /etc/systemd/system/task-tracker.service << 'EOF'
[Unit]
Description=Avalon Task Tracker Server
After=network-online.target
Wants=network-online.target

[Service]
Type=simple
User=ubuntu
WorkingDirectory=/home/ubuntu/task-tracker
Environment="STATE_FILE=/home/ubuntu/task-tracker/state.json"
Environment="EC2_RELAY_URL=http://127.0.0.1:8766/send-signal"
Environment="RELAY_TOKEN=REPLACE_WITH_YOUR_TOKEN"
ExecStart=/home/ubuntu/task-tracker/venv/bin/python server.py
Restart=always
RestartSec=5
StandardOutput=journal
StandardError=journal
SyslogIdentifier=task-tracker

[Install]
WantedBy=multi-user.target
EOF

sudo systemctl daemon-reload
sudo systemctl enable task-tracker
sudo systemctl start task-tracker
sudo systemctl status task-tracker
```

Note: `EC2_RELAY_URL` uses `127.0.0.1` since both services run on the same EC2 instance.

### 2.4 Verify the server

```bash
# From any device:
curl http://34.208.73.189:8765/health
# Expected: {"status": "ok", "date": "2026-03-11"}

curl http://34.208.73.189:8765/state
# Expected: JSON with all tasks false, active_window true/false depending on time

# Simulate a button press:
curl -X POST http://34.208.73.189:8765/press \
  -H "Content-Type: application/json" \
  -d '{"owner": "ryker", "task": "laundry"}'
# Expected: {"status": "ok"} or {"status": "outside_window"}
```

### 2.5 Watch logs

```bash
sudo journalctl -u task-tracker -f
```

---

## Part 3 — ESPHome Secrets

### 3.1 Fill in secrets.yaml

```bash
cd task-tracker/esphome
cp secrets.yaml.template secrets.yaml
```

Edit `secrets.yaml`:

```yaml
wifi_ssid: "Avalon"
wifi_password: "YourWiFiPassword"
api_encryption_key: "$(openssl rand -base64 32)"
ota_password: "choose_something"
pi_ip: "34.208.73.189"
relay_token: "your_token"
```

**Never commit secrets.yaml.** It is in `.gitignore`.

---

## Part 4 — Flash the Buttons (9× Seeed XIAO ESP32-C6)

Flash each button one at a time. Label each board before flashing.

### 4.1 Install ESPHome (if not already)

```bash
pip install esphome
```

### 4.2 Flash each button

Connect the XIAO ESP32-C6 via USB-C. Then for each button yaml:

```bash
cd task-tracker/esphome

# First flash (wired):
esphome run button-ryker-laundry.yaml --device /dev/cu.usbmodem*

# Subsequent flashes (OTA, once on WiFi):
esphome upload button-ryker-laundry.yaml --device button-ryker-laundry.local
```

Repeat for all 7 buttons:
- button-ryker-laundry
- button-ryker-teeth
- button-ryker-plates
- button-ryker-pills
- button-logan-laundry
- button-logan-teeth
- button-logan-plates

### 4.3 Test each button

After flashing, press the physical button. Watch the EC2 logs:

```bash
ssh -i ~/.ssh/the-pem-key.pem ubuntu@34.208.73.189 \
  "sudo journalctl -u task-tracker -f"
```

You should see: `Recorded: ryker / laundry`

The button should play two clicks on success.

**Outside 6–9:30 AM window:** The server returns `outside_window` and the
button plays three quick clicks. This is expected.

---

## Part 5 — Flash the Display (Waveshare 7.5" V2)

### 5.1 Verify pi_ip in secrets.yaml

The display config references `!secret pi_ip` which should be `34.208.73.189`.

### 5.2 Flash the display board

The Waveshare ESP32 driver board connects via USB.

```bash
cd task-tracker/esphome
esphome run display-front-door.yaml
```

For OTA updates:
```bash
esphome upload display-front-door.yaml --device display-front-door.local
```

### 5.3 Verify display behavior

**During active window (6:00–9:30 AM):**
- Left column: Ryker's tasks with ( ) (pending) or [X] (done)
- Right column: Logan's tasks

**Outside active window:**
- Shows "Good morning! / Tasks open 6:00 – 9:30 AM"

**Both kids done:**
- Shows "All done! / Ryker [X]  |  Logan [X]"

The display polls the server every 60 seconds.

---

## Part 6 — Signal Message Verification

The system sends **one Signal message per day**, at 9:30 AM Pacific.

### Format

```
Ryker done | Logan done
Ryker done | Logan missed: teeth, plates
Ryker missed: pills | Logan missed: teeth, plates
```

### Force a test

```bash
# Send a test message directly through the relay:
curl -X POST http://34.208.73.189:8766/send-signal \
  -H "Content-Type: application/json" \
  -H "X-Relay-Token: your_token_here" \
  -d '{"message": "Ryker done | Logan missed: teeth, plates"}'
```

---

## Part 7 — Daily Reset Verification

The 3:00 AM reset wipes all task state. To verify without waiting:

```bash
# Check current state
curl http://34.208.73.189:8765/state | python3 -m json.tool

# Manually wipe state (on EC2):
ssh -i ~/.ssh/the-pem-key.pem ubuntu@34.208.73.189 \
  "echo '{}' > ~/task-tracker/state.json && sudo systemctl restart task-tracker"

# State should reload fresh for today
curl http://34.208.73.189:8765/state | python3 -m json.tool
```

---

## Troubleshooting

| Symptom | Check |
|---|---|
| Button plays three clicks always | Is it outside 6–9:30 AM window? Check EC2 server time |
| Button plays nothing | Check WiFi — button may not be reaching server |
| Display shows stale data | Check EC2 server is running: `curl http://34.208.73.189:8765/health` |
| Display shows "Good morning!" during active hours | Server may be down or display can't reach EC2 |
| No Signal message at 9:30 | Check server logs for relay errors; verify signal relay is running |
| Signal relay returns 401 | Token mismatch — verify same RELAY_TOKEN on server and relay |
| signal-cli not found | Update SIGNAL_CLI path in signal_relay.py or env var |
| State resets unexpectedly | Corrupt state.json — server auto-recovers on restart |
| HTTP requests from buttons fail silently | Ensure `verify_ssl: false` is in `.base-button.yaml` http_request config |

---

## Infrastructure Reference

```
EC2 Instance: 34.208.73.189
  SSH: ssh -i ~/.ssh/the-pem-key.pem ubuntu@34.208.73.189
  Services:
    task-tracker (port 8765) — Flask server, systemd
    signal-relay (port 8766) — signal-cli relay, systemd
  Security group: ports 22, 8765, 8766 open

WiFi: Avalon (home network)
  Buttons and display connect via WiFi, POST/GET to EC2 over internet
```

## File Reference

```
task-tracker/
├── esphome/
│   ├── secrets.yaml.template   ← copy → secrets.yaml, fill in values
│   ├── .base-common.yaml       ← WiFi/API/OTA shared config
│   ├── .base-button.yaml       ← button behavior (HTTP POST, buzzer feedback)
│   ├── .base-display.yaml      ← display SPI/fonts/polling base
│   ├── button-*.yaml           ← one per physical button (7 total)
│   └── display-front-door.yaml ← e-ink display config + render lambda
├── server/
│   ├── server.py               ← Flask server (runs on EC2)
│   ├── requirements.txt        ← pip deps
│   └── task-tracker.service    ← systemd unit (reference — actual is on EC2)
├── ec2/
│   └── signal_relay.py         ← Signal relay Flask app
└── docs/
    └── *.md                    ← documentation
```

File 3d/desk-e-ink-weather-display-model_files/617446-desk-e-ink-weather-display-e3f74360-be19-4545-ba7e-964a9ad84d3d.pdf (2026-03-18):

## Desk e-ink weather

## display

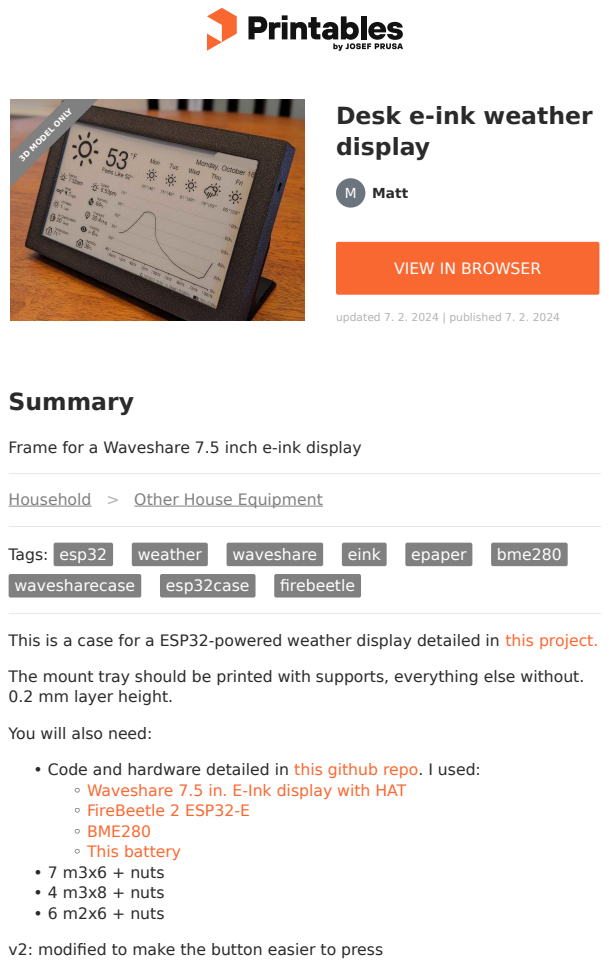
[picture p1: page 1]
Summary; Household; Other House Equipment; Tags: esp32; weather; waveshare; eink; epaper; bme280; wavesharecase; esp32case; firebeetle; Waveshare 7.5 in. E-Ink display with HAT; FireBeetle 2 ESP32-E; BME280; This battery; 7 m3x6 + nuts; 4 m3x8 + nuts; 6 m2x6 + nuts; Matt; updated 7. 2. 2024 | published 7. 2. 2024; 3D MODEL ONLY

VIEW IN BROWSER (https://printables.com/model/617446-desk-e-ink-weather-display)

Frame for a Waveshare 7.5 inch e-ink display

This is a case for a ESP32-powered weather display detailed in this project. (https://github.com/lmarzen/esp32-weather-epd/)

The mount tray should be printed with supports, everything else without.
0.2 mm layer height.

You will also need:

Code and hardware detailed in this github repo. (https://github.com/lmarzen/esp32-weather-epd/) I used:

v2: modified to make the button easier to press

# Model files

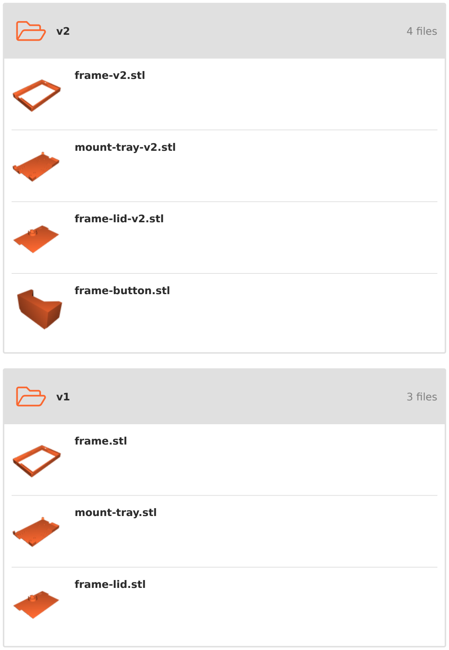
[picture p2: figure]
4 files; 3 files; frame-v2.stl; mount-tray-v2.stl; frame-lid-v2.stl; frame-button.stl; frame.stl; mount-tray.stl; frame-lid.stl

## License

This work is licensed under a

Creative Commons (4.0 International License) (http://creativecommons.org/licenses/by-nc-sa/4.0/)

battery-clip.stl

wire-clip.stl

stand-right-60.stl

stand-left-60.stl

stand-right-45.stl

stand-left-45.stl

stand-right-75.stl

stand-left-75.stl

Attribution—Noncommercial—Share Alike (http://creativecommons.org/licenses/by-nc-sa/4.0/)

✖ | Sharing without ATTRIBUTION
✔ | Remix Culture allowed
✖ | Commercial Use
✖ | Free Cultural Works
✖ | Meets Open Definition

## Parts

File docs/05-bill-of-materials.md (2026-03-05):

# Bill of Materials

Last updated: 2026-02-26

## On Hand

- 9× Seeed XIAO ESP32-C6 boards
- 1× Waveshare 7.5" e-ink raw panel (800×480, B/W)
- 1× Waveshare e-Paper ESP32 Driver Board ([B07M5CNP3B](https://www.amazon.com/dp/B07M5CNP3B))
- Bambu Lab 3D printers + filament (PLA/PETG)
- Soldering iron + solder
- USB-C cables for flashing/charging
- Command strips for wall mounting

## To Purchase

### 1. Passive Piezo Buzzers
- **Product**: Cylewet 5V 2-pin passive electromagnetic buzzer, 10-pack
- **Quantity**: 1 pack (need 9, rest are spares)
- **Price**: ~$6
- **Specs**: 2-pin, passive, ~12mm diameter, 3-5V operating range
- **Link**: Search "Cylewet 10pcs 5V passive buzzer electromagnetic beeper" on Amazon
- **Notes**: Passive (not active) — allows PWM tone control via ESPHome LEDC output. Solder one pin to GPIO, one to GND. Works at 3.3V. Enables per-task sounds, victory jingles, ascending scales as tasks complete.

### 2. LiPo Batteries — Button Units
- **Product**: Liter 3.7V 400mAh 502035 LiPo
- **Quantity**: 10 (9 units + 1 spare)
- **Price**: ~$8 each, ~$80 total
- **Dimensions**: 5mm × 20mm × 35mm
- **Connector**: JST PH 2.0mm (cut off, solder bare wires to XIAO BAT+/BAT- pads)
- **Link**: Search "Liter 502035 400mAh" on Amazon
- **Notes**: XIAO BAT- pad near D8 silkscreen, BAT+ near D5. Built-in USB-C charging on XIAO handles recharging.

### 3. LiPo Battery — E-ink Display
- **Product**: Liter 3.7V 3000mAh 105050 LiPo
- **Quantity**: 1
- **Price**: ~$10
- **Dimensions**: 9.9mm × 50mm × 48mm (fits behind 170×111mm panel)
- **Connector**: JST PH 2.0mm (cut off, solder to TP4056 battery pads)
- **Link**: [B09FL7QD88](https://www.amazon.com/dp/B09FL7QD88)
- **Notes**: Verify polarity with multimeter before connecting. Some units ship with red/black swapped on JST.

### 4. TP4056 USB-C LiPo Charger Modules
- **Product**: HiLetgo TP4056 Type-C USB 5V 1A 18650 Lithium Battery Charger Module
- **Quantity**: 3-pack
- **Price**: ~$6
- **Link**: Search "HiLetgo TP4056 Type-C 3pcs" on Amazon
- **Notes**: Get version WITH protection (DW01 chip) for overdischarge protection. Wiring: USB-C → TP4056 → battery → Waveshare 5V/GND pins. Only needed for e-ink display (XIAO boards have built-in charging).

### 5. Tactile Pushbutton Switches
- **Product**: DAOKI 6×6×5mm tactile switches, 100-pack
- **Quantity**: 1 pack (need 9, rest are spares)
- **Price**: ~$6
- **Specs**: Through-hole, 4-pin, momentary, DC12V 50mA rated
- **Link**: [B01CGMP9GY](https://www.amazon.com/dp/B01CGMP9GY)
- **Notes**: Solder two wires per switch (GPIO + GND). Mount under 3D-printed plunger cap for kid-friendly feel. 5mm button height provides good tactile feedback.

### 6. Hookup Wire
- **Product**: BNTECHGO 22 AWG Silicone Wire (red + black, 10ft each)
- **Quantity**: 1 kit
- **Price**: ~$6
- **Specs**: 22 gauge stranded tinned copper, 60 strands × 0.08mm, 1.7mm OD, silicone insulation
- **Link**: Search "BNTECHGO 22 AWG silicone red black" on Amazon
- **Notes**: Silicone insulation rated -60°C to +200°C, won't melt during soldering. Use for switch-to-GPIO and battery-to-pad connections.

### 7. Heat Shrink Tubing
- **Product**: Heat shrink tubing assortment kit (580pcs, 11 sizes)
- **Quantity**: 1 kit
- **Price**: ~$7
- **Primary sizes needed**:
  - 1/12" (2.1mm): for battery wire solder joints
  - 1/8" (3.2mm): for 22 AWG hookup wire joints
- **Link**: Search "580pcs heat shrink tubing assortment" on Amazon
- **Notes**: Critical for LiPo safety — insulate all battery solder connections.

## Cost Summary

| Category | Est. Cost |
|---|---|
| Passive piezo buzzers (10-pack) | $6 |
| Button unit batteries (10×) | $80 |
| E-ink display battery (1×) | $10 |
| TP4056 charger modules (3-pack) | $6 |
| Tactile switches (100-pack) | $6 |
| Hookup wire | $6 |
| Heat shrink tubing | $7 |
| **Total** | **~$121** |

## Power Architecture

### Button Units (×9)
```
[3.7V 400mAh LiPo] → solder to XIAO BAT+/BAT- pads
                       ↕ (USB-C plugged in = charges battery via XIAO onboard charger)
[XIAO ESP32-C6] → deep sleep 15µA → months between charges
```

### E-ink Display (×1)
```
[USB-C] → [TP4056 w/ protection] → [3.7V 3000mAh LiPo] → [Waveshare 5V/GND pins]
           (charging)                (storage)               (power)
```

## 3D-Printed Components (designed in OpenSCAD, printed on Bambu Lab)

- **Button unit enclosure**: Houses XIAO + battery + tact switch + buzzer. USB-C port access for charging/flashing. Wall-mountable. Color-coded or labeled per kid.
- **Button plunger cap**: Large kid-friendly dome/palm-slap target (~55mm diameter) with 3-5mm printed travel and spring-back mechanism. Presses down on 6×6mm tact switch at bottom of travel.
- **E-ink display frame**: Mounts 7.5" panel + driver board + battery + TP4056. Wall-mountable at front door.

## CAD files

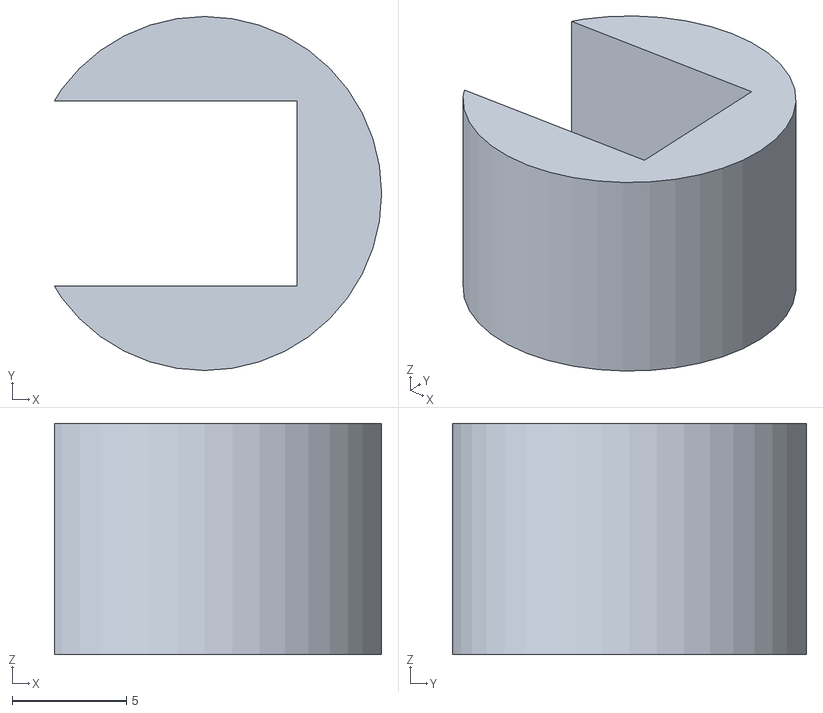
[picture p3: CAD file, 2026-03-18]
3d/button-enclosure-pillar-test.stl
14.3 x 15.5 x 10.1

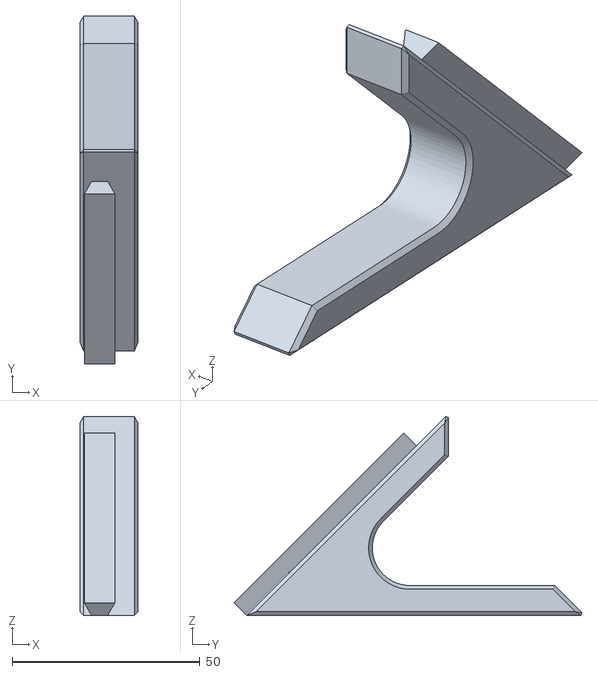
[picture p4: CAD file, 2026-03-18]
3d/desk-e-ink-weather-display-model_files/stand-right-45.stl
15.5 x 92.7 x 53.0

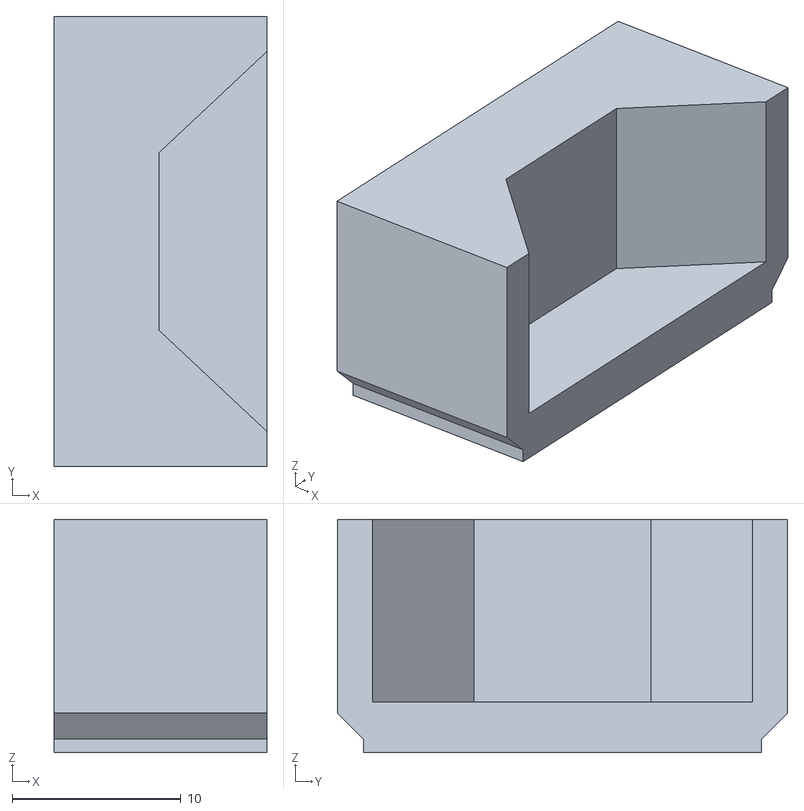
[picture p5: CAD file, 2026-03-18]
3d/desk-e-ink-weather-display-model_files/v2/frame-button.stl
12.6 x 26.7 x 13.8

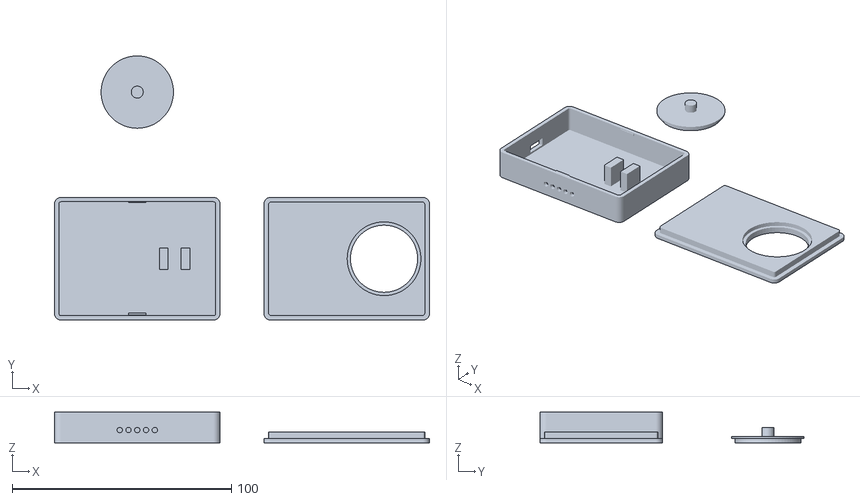
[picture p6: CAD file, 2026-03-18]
3d/button-enclosure.stl
170.9 x 120.4 x 14.1

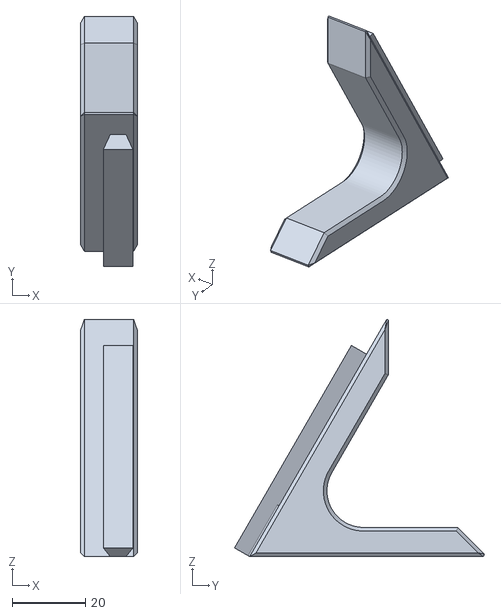
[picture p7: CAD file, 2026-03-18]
3d/desk-e-ink-weather-display-model_files/stand-left-60.stl
15.5 x 68.4 x 65.0

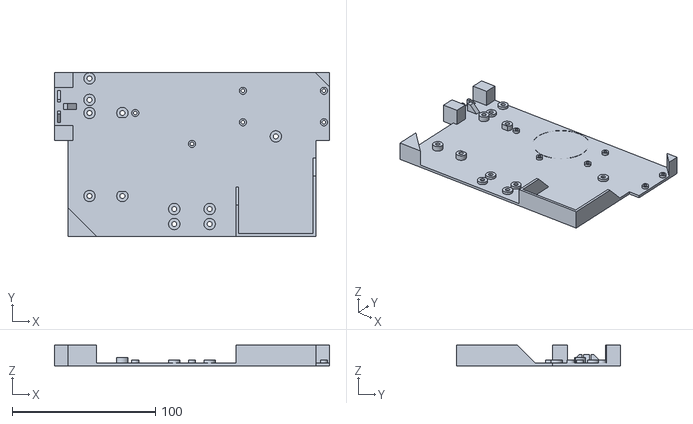
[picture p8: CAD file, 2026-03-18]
3d/desk-e-ink-weather-display-model_files/v2/mount-tray-v2.stl
192.1 x 114.7 x 14.6

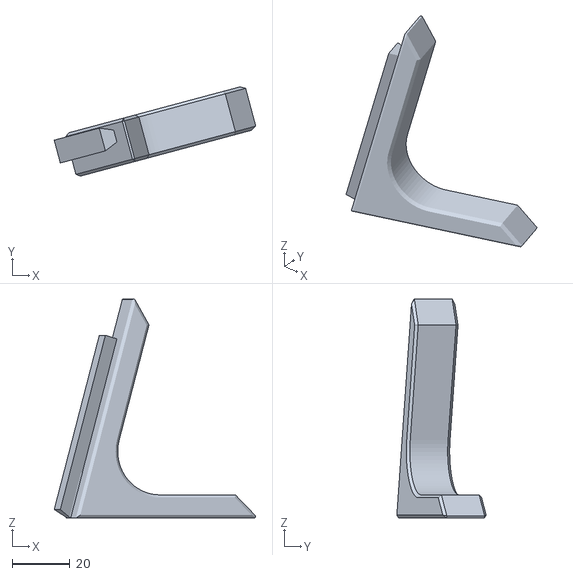
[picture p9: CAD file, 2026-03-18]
3d/desk-e-ink-weather-display-model_files/stand-right-75.stl
69.6 x 30.8 x 75.6

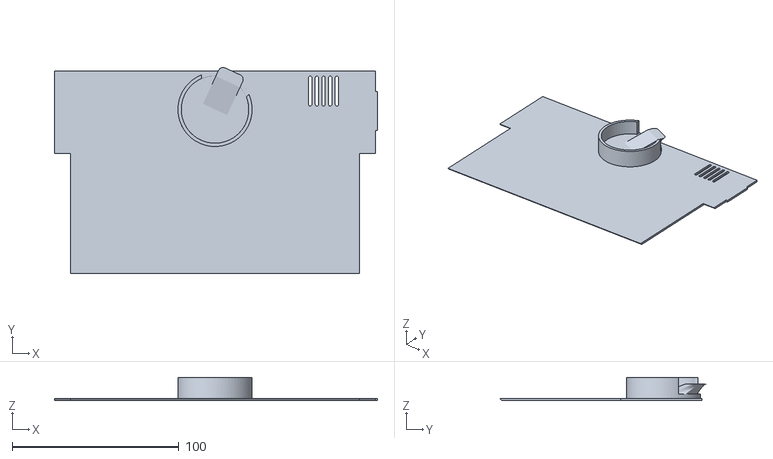
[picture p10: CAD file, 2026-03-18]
3d/desk-e-ink-weather-display-model_files/v2/frame-lid-v2.stl
193.9 x 123.7 x 14.0

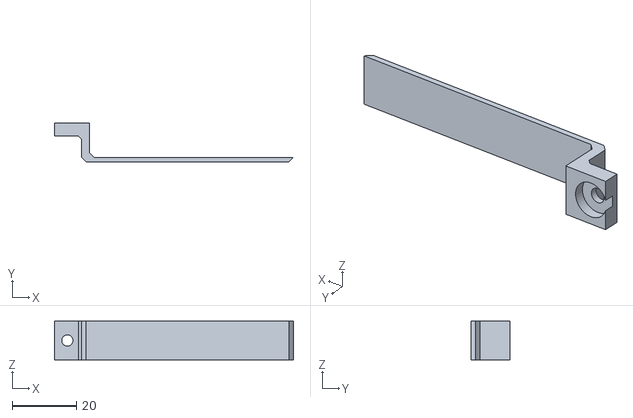
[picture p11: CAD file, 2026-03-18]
3d/desk-e-ink-weather-display-model_files/battery-clip.stl
74.3 x 12.0 x 12.0

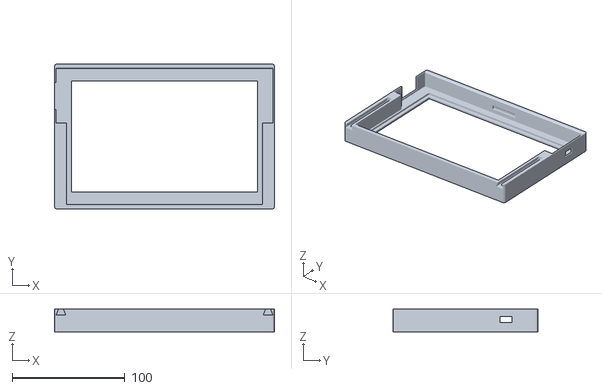
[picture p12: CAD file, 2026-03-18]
3d/desk-e-ink-weather-display-model_files/v2/frame-v2.stl
195.0 x 128.5 x 20.0

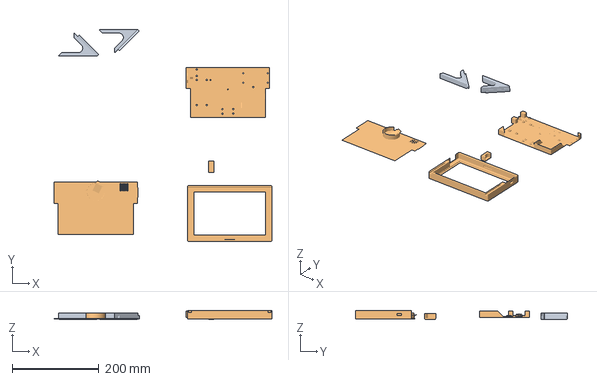
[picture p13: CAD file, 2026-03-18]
3d/stand-left-45.3mf
503.2 x 488.4 x 20.8 mm
stand-left-45
frame-button

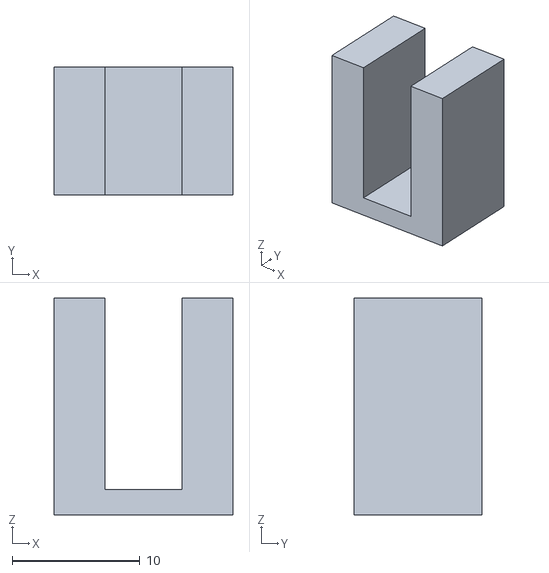
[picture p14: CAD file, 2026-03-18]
3d/button-enclosure-rectangle-piller-test.stl
14.0 x 10.0 x 17.0

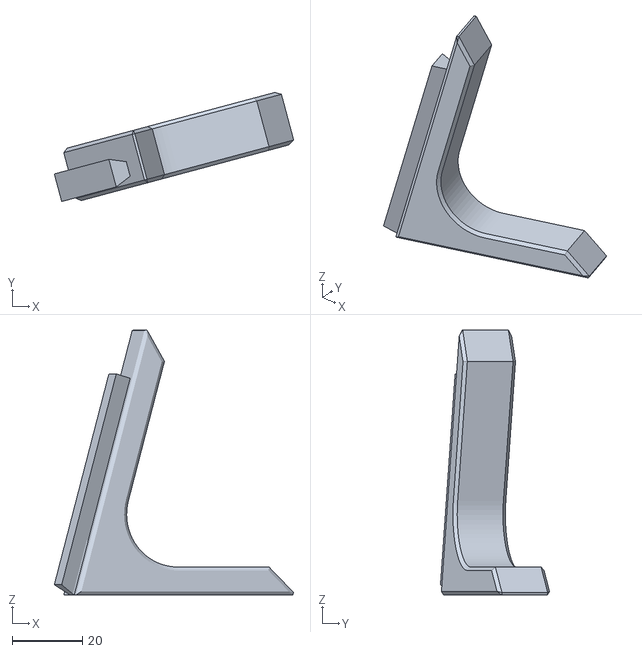
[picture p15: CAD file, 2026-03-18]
3d/desk-e-ink-weather-display-model_files/stand-left-75.stl
68.3 x 31.1 x 75.6

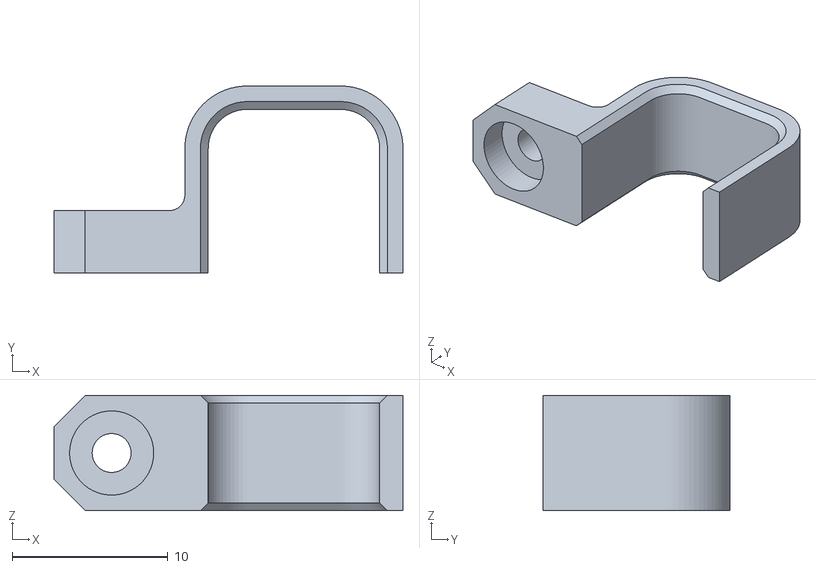
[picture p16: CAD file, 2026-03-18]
3d/desk-e-ink-weather-display-model_files/wire-clip.stl
22.4 x 12.0 x 7.40

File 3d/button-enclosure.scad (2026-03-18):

// button-enclosure.scad
// Enclosure for task-tracker button: XIAO ESP32-C6 + battery + buzzer + tact switch
// Flat back for surface adhesion. Large press cap over 6mm tact switch.
// Two pieces: base (open-top box) and lid (with integrated button cap).

// ── Measured component dimensions ───────────────────────
// XIAO ESP32-C6
xiao_l = 21.0;        // mm, length
xiao_w = 17.5;        // mm, width
xiao_h = 4.53;        // mm, total height (PCB + components)

// USB-C port (on xiao_w edge, centered)
usbc_w = 8.88;        // mm
usbc_h = 3.16;        // mm
usbc_protrude = 1.4;  // mm, sticks out from board edge

// Tact switch
sw_size = 6.0;        // mm, square body footprint
sw_pins = 7.5;        // mm, square channel size (pins + solder diagonal is 10.21mm)
sw_h = 1.66;          // mm, button press height

// Buzzer
buz_dia = 11.65;      // mm
buz_h = 7.77;         // mm (not counting prongs/solder)

// Battery
bat_w = 51.36;        // mm
bat_l = 51.36;        // mm
bat_h = 9.83;         // mm

// ── Enclosure parameters ────────────────────────────────
wall = 2.0;           // mm
tol = 0.3;            // mm, clearance
corner_r = 3.0;       // mm, rounded corners

// ── Layout ──────────────────────────────────────────────
// All components sit side by side on the floor.
// Pillar for tact switch rises from floor next to battery.
// XIAO board and buzzer also beside battery.
//
// Internal cavity sizing:
// Width: battery + pillar diameter + clearance gap
pillar_dia = sw_pins + 8;                 // 15.5mm — channel + walls
cav_w = bat_w + 2*tol + pillar_dia + 4;  // battery + gap + pillar + margin
cav_l = bat_l + 2*tol;                    // battery length + clearance
cav_h = max(bat_h, buz_h) + tol          // tallest floor component
      + sw_h + tol;                        // switch on top + clearance

// Outer dimensions
outer_w = cav_w + 2*wall;
outer_l = cav_l + 2*wall;
outer_h = cav_h + wall;   // base has floor (flat back), open top

// Pillar X offset — centered in the space beside the battery
pillar_x = (bat_w/2 + 2*tol + pillar_dia/2) / 2;

// Button cap
cap_dia = 30.0;       // mm, large press surface
cap_travel = 1.0;     // mm, how far it can depress
cap_post_dia = 5.5;   // mm, post that contacts tact switch (just under 6mm)

// Lid
lid_h = wall + cap_travel + 1.0;  // lid thickness + room for button travel

// ── Helper: rounded box ─────────────────────────────────
module rounded_box(w, l, h, r) {
    hull() {
        for (x = [-w/2+r, w/2-r])
            for (y = [-l/2+r, l/2-r])
                translate([x, y, 0])
                    cylinder(r=r, h=h, $fn=40);
    }
}

// ── Base ────────────────────────────────────────────────
module base() {
    difference() {
        // Outer shell
        rounded_box(outer_w, outer_l, outer_h, corner_r);

        // Inner cavity (open top)
        translate([0, 0, wall])
            rounded_box(cav_w, cav_l, cav_h + 0.01, corner_r - wall);

        // USB-C access hole — on -X edge (opposite side from pillar)
        // Board sits on the floor, USB port near the bottom
        usb_z = wall + 1;  // slightly above floor
        translate([-outer_w/2 - 0.01, -(usbc_w + 2*tol)/2, usb_z])
            cube([wall + 0.02, usbc_w + 2*tol, usbc_h + 2*tol]);

        // Buzzer sound holes — on -Y wall, buzzer sits on the floor
        for (i = [-2:2]) {
            translate([i * 4, -outer_l/2 - 0.01, wall + buz_h/2])
                rotate([-90, 0, 0])
                    cylinder(d=2.5, h=wall + 0.02, $fn=20);
        }
    }

    // Snap clip ledges — small ridges on inner walls near the top
    // The lid's flexible tabs catch under these when pressed down
    snap_w = 8;        // width of each ledge
    snap_depth = 0.8;  // how far ledge protrudes inward
    snap_h = 1.0;      // height of ledge
    snap_z = outer_h - snap_h - 0.5;  // just below top edge
    for (y = [-1, 1]) {
        translate([-(snap_w)/2, y * (cav_l/2 - snap_depth/2), snap_z])
            cube([snap_w, snap_depth, snap_h]);
    }

    // Switch mount — two rectangular towers, 6mm apart
    // Switch body sits between them, glued on both flat sides
    // Pins/wires extend freely out the open sides
    pillar_h = cav_h - sw_h;  // everything except the switch itself
    tower_w = 4;              // mm, thickness of each tower
    tower_l = sw_size + 4;    // mm, length (wider than switch for glue surface)
    gap = sw_size;            // mm, exactly 6mm between towers

    for (side = [-1, 1]) {
        translate([pillar_x + side * (gap/2 + tower_w/2) - tower_w/2, -tower_l/2, wall])
            cube([tower_w, tower_l, pillar_h]);
    }
}

// ── Lid ─────────────────────────────────────────────────
// The lid hole is sized for the cap stem to pass through, but NOT the flange.
// Assembly: insert button cap from underside of lid (flange catches on inside),
// then place lid on base. Cap is trapped — can't go up (flange) or down (base).
cap_stem_dia = cap_dia;           // stem passes through
flange_dia = cap_dia + 3;        // flange is wider, caught inside

// Snap clip dimensions (must match base ledges)
snap_w = 8;
snap_depth = 0.8;
snap_h = 1.0;
lip_len = 3.0;  // how far the lid lip extends into the base

module lid() {
    difference() {
        union() {
            // Lid plate
            rounded_box(outer_w, outer_l, wall, corner_r);

            // Friction-fit lip (inserts into base)
            translate([0, 0, -lip_len])
                rounded_box(cav_w - tol, cav_l - tol, lip_len, corner_r - wall);

            // Snap tabs — flexible arms on the lip that catch under base ledges
            // Angled tip helps them flex inward during insertion, then spring out
            for (y = [-1, 1]) {
                translate([-(snap_w)/2, y * (cav_l/2 - tol/2 - wall) + (y > 0 ? -snap_depth : 0), -lip_len])
                    cube([snap_w, snap_depth, lip_len]);
                // Catch nub at bottom of each tab
                translate([-(snap_w)/2, y * (cav_l/2 - tol/2 - wall) + (y > 0 ? -snap_depth : 0), -lip_len])
                    cube([snap_w, snap_depth + 0.5, snap_h]);
            }
        }

        // Through-hole for cap stem (offset to match pillar position)
        translate([pillar_x, 0, -lip_len - 0.01])
            cylinder(d=cap_stem_dia + 2*tol, h=wall + lip_len + 0.02, $fn=60);

        // Flange recess on underside of lid
        // Deep enough for flange thickness (1mm) + travel (1mm)
        translate([pillar_x, 0, -lip_len - 0.01])
            cylinder(d=flange_dia + 2*tol, h=1.0 + cap_travel + 0.01, $fn=60);
    }
}

// ── Button cap ──────────────────────────────────────────
// Assembled from underside of lid:
//   [post] → [flange] → [stem through lid] → [press surface on top]
module button_cap() {
    // Press surface — visible on top of lid
    cylinder(d=cap_stem_dia, h=2.0, $fn=60);

    // Flange — sits in recess under lid, prevents cap from coming out the top
    translate([0, 0, -1.0])
        cylinder(d=flange_dia, h=1.0, $fn=60);

    // Post underneath flange — reaches down to contact tact switch
    translate([0, 0, -1.0 - cap_travel - 3])
        cylinder(d=cap_post_dia, h=cap_travel + 3, $fn=30);
}

// ── Assembly view ───────────────────────────────────────
// Uncomment the section you want to export as STL.

// -- Full assembly --
base();

translate([outer_w + 20, 0, wall])
    rotate([180, 0, 0])
        lid();

translate([0, outer_l + 20, 2.0])
    rotate([180, 0, 0])
        button_cap();

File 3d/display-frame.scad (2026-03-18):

// display-frame.scad
// Freestanding frame for Waveshare 7.5" V2 e-ink display
// with ESP32 driver board and LiPo battery enclosed behind.

// ── Display panel ───────────────────────────────────────
disp_w = 170.2;       // mm, horizontal
disp_h = 111.2;       // mm, vertical
disp_t = 1.18;        // mm, thickness
active_w = 163.2;     // mm, visible area width
active_h = 97.92;     // mm, visible area height

// ── Driver board ────────────────────────────────────────
pcb_w = 48.25;        // mm
pcb_h = 29.46;        // mm
pcb_t = 1.6;          // mm (standard PCB)

// ── Battery ─────────────────────────────────────────────
bat_w = 51.36;        // mm
bat_h = 51.36;        // mm
bat_t = 9.83;         // mm

// ── Frame parameters ────────────────────────────────────
wall = 2.0;           // mm, wall thickness
bezel = 3.5;          // mm, front bezel overlap around display
tol = 0.4;            // mm, tolerance/clearance per side
back_depth = bat_t + pcb_t + 4;  // mm, rear cavity depth (battery + board + clearance)

// ── Derived dimensions ──────────────────────────────────
// Outer shell
outer_w = disp_w + 2*tol + 2*wall;
outer_h = disp_h + 2*tol + 2*wall;
outer_d = wall + disp_t + tol + back_depth + wall;  // front wall + display + gap + cavity + back wall

// Display pocket (front, recessed into front face)
pocket_w = disp_w + 2*tol;
pocket_h = disp_h + 2*tol;
pocket_d = disp_t + tol;

// Front window (exposes active area)
win_w = active_w + 2;  // slight margin
win_h = active_h + 2;

// Ribbon cable slot — display ribbon exits bottom edge
ribbon_slot_w = 30;
ribbon_slot_h = 5;

// ── Kickstand ───────────────────────────────────────────
stand_angle = 15;     // degrees from vertical
stand_w = 40;
stand_t = 3;
stand_len = outer_h * 0.7;

// ── Main frame ──────────────────────────────────────────
module frame() {
    difference() {
        // Outer shell — rounded box
        translate([0, 0, outer_d/2])
            cube([outer_w, outer_h, outer_d], center=true);

        // Front display pocket (from front face)
        translate([0, 0, -0.01])
            translate([0, 0, wall + pocket_d/2])
                cube([pocket_w, pocket_h, pocket_d + 0.02], center=true);

        // Front window (through front wall, exposing active area)
        translate([0, 0, -0.01])
            cube([win_w, win_h, wall + 0.02 + pocket_d], center=true);

        // Rear cavity (from back, for driver board + battery)
        translate([0, 0, outer_d - wall - back_depth/2 + 0.01])
            cube([outer_w - 2*wall, outer_h - 2*wall, back_depth + 0.02], center=true);

        // Ribbon cable slot — bottom edge, connecting front pocket to rear cavity
        translate([0, -outer_h/2 + wall/2, wall + pocket_d + (outer_d - wall - pocket_d - wall)/2])
            cube([ribbon_slot_w, wall + 2, outer_d], center=true);

        // USB access hole — bottom edge, for charging
        translate([outer_w/2 - wall/2 - 15, -outer_h/2 - 0.01, outer_d - wall - 8])
            cube([12, wall + 0.02, 8]);
    }
}

// ── Back cover (snap-on or friction fit) ────────────────
module back_cover() {
    lip = 1.5;  // mm, lip that inserts into cavity

    translate([0, 0, 0]) {
        difference() {
            union() {
                // Flat cover plate
                cube([outer_w, outer_h, wall], center=true);
                // Lip to fit inside cavity
                translate([0, 0, -wall/2 - lip/2])
                    cube([outer_w - 2*wall - tol, outer_h - 2*wall - tol, lip], center=true);
            }

            // USB access hole matching frame
            translate([outer_w/2 - wall/2 - 15 - outer_w/2, -outer_h/2 + wall - outer_h/2 + outer_h/2 - 0.01, -wall/2 - lip - 0.01])
                cube([12, wall + 0.02, wall + lip + 0.02]);

            // Ventilation slots
            for (i = [-2:2]) {
                translate([i * 20, 0, 0])
                    cube([10, 40, wall + 0.02], center=true);
            }
        }
    }
}

// ── Kickstand ───────────────────────────────────────────
module kickstand() {
    difference() {
        union() {
            // Main strut
            cube([stand_w, stand_t, stand_len], center=true);
            // Hinge tab (top)
            translate([0, 0, stand_len/2])
                cylinder(h=stand_t, r=stand_w/6, center=true, $fn=30);
        }
        // Hinge hole
        translate([0, 0, stand_len/2])
            cylinder(h=stand_t + 0.1, r=1.6, center=true, $fn=20);
    }
}

// ── Assembly ────────────────────────────────────────────
// Uncomment the part you want to export:

// Main frame
frame();

// Back cover — offset for printing
translate([outer_w + 10, 0, wall/2])
    back_cover();

// Kickstand — offset for printing
translate([0, outer_h + 10, stand_t/2])
    kickstand();

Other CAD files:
3d/desk-e-ink-weather-display-model_files/stand-left-45.stl
3d/desk-e-ink-weather-display-model_files/stand-right-60.stl
3d/desk-e-ink-weather-display-model_files/v1/frame.stl
3d/desk-e-ink-weather-display-model_files/v1/frame-lid.stl
3d/desk-e-ink-weather-display-model_files/v1/mount-tray.stl
3d/stand-left-45.stl

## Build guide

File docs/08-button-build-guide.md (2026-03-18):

# Button Build Guide
### AM Routine Tracker — Avalon Household

**Print this doc. Build one button at a time. Don't skip steps.**

---

## Before You Start

### Tools needed
- Soldering iron + solder
- Wire strippers
- Multimeter
- Heat gun (or lighter) for heat shrink
- USB-C cable (for flashing)
- Laptop with terminal open
- Tweezers
- Isopropyl alcohol + cotton swab (flux cleanup)

### Parts per button unit
| Part | Notes |
|---|---|
| 1x Seeed XIAO ESP32-C6 | The brains |
| 1x 3.7V 400mAh LiPo (Liter 502035) | 5x20x35mm |
| 1x 6x6x5mm tactile pushbutton switch | 4-pin through-hole |
| 1x Passive piezo buzzer (~12mm, 2-pin) | NOT active — must be passive |
| ~15cm red 22 AWG silicone wire | Switch wire |
| ~15cm black 22 AWG silicone wire | Switch GND wire |
| ~10cm red wire | Buzzer wire |
| ~10cm black wire | Buzzer GND wire |
| 2x small heat shrink pieces | Battery solder joints |
| 1x 3D-printed enclosure + plunger | Print before assembly |

---

## GPIO Pin Assignments

These are fixed. Use them. Don't improvise.

| Function | XIAO Pin Label | GPIO # |
|---|---|---|
| Tact switch input | D1 | GPIO1 |
| Passive buzzer output | D2 | GPIO2 |
| Battery positive | BAT+ pad | near D5 silkscreen |
| Battery negative | BAT- pad | near D8 silkscreen |
| Built-in status LED | (onboard) | GPIO15 (active low) |

> **WARNING — Pin numbering**: The XIAO ESP32-C6 pin labels (D0, D1, D2...) do NOT match GPIO numbers above D2. The mapping is: D0=GPIO0, D1=GPIO1, D2=GPIO2, D3=GPIO21, D4=GPIO22, D5=GPIO23. Do NOT use GPIO3 — it is the RF switch power pin (board-internal).

> **Buzzer note**: LEDC PWM and rtttl do NOT work on ESP32-C6 with the esp-idf framework (outputs 0V). The firmware uses plain GPIO toggle to produce audible clicks on the passive buzzer. This is a known platform limitation.

---

## Step 1 — Inspect the XIAO board

- [ ] No bent pins, no visible damage
- [ ] USB-C port is clean
- [ ] Find the **BAT+** pad (small gold pad near D5 label on back of board)
- [ ] Find the **BAT-** pad (small gold pad near D8 label on back of board)

> These pads are small. Use a magnifier if needed. Soldering to the wrong pad will damage the board.

---

## Step 2 — Prep the LiPo battery

**SAFETY FIRST.** LiPo batteries can catch fire if shorted or punctured. The two bare wire ends must never touch each other.

1. The battery has a JST connector — **cut it off** leaving ~5cm of wire attached to the battery
2. **Immediately** slide a piece of heat shrink over each wire end and shrink it down — leave only ~4mm of wire exposed at the tip. Do this before anything else. Both ends insulated before you proceed.
3. Strip the 4mm tips
4. Tin both wire tips with solder

---

## Step 3 — Solder battery to XIAO

1. Tin the BAT+ and BAT- pads on the back of the XIAO
2. **Verify polarity with your multimeter** before soldering:
   - Red wire = positive = BAT+ pad
   - Black wire = negative = BAT- pad
   - Some LiPo units ship with reversed JST colors — measure, don't assume
3. Solder red wire to BAT+ pad
4. Solder black wire to BAT- pad
5. Check that no wire strands are poking sideways toward adjacent pads
6. Tug gently on each wire — joints should not move

> Note: there's no joint to heat-shrink on the board side — the solder pad itself is the joint. The heat shrink you applied in Step 2 protects the battery-end wires from shorting against each other.

> **TEST**: Plug in USB-C. The orange charge LED on the XIAO should light up. If it doesn't, STOP — check polarity and solder joints before continuing.

---

## Step 4 — Flash firmware BEFORE soldering more components

Flash now while USB-C access is easy and no other wires are in the way.

1. Connect the XIAO to your laptop via USB-C
2. Verify the board is detected:
   ```
   ls /dev/cu.usbmodem*
   ```
3. Create the device YAML (copy from `button-ryker-teeth.yaml` and change substitutions):
   ```yaml
   substitutions:
     device_name: button-KIDNAME-TASK
     owner: KIDNAME
     task: TASK
     pi_ip: !secret pi_ip

   packages:
     common: !include .base-common.yaml
     button: !include .base-button.yaml
   ```
4. Make sure `secrets.yaml` has your WiFi credentials, API key, OTA password, and `pi_ip`
5. Clean and flash:
   ```
   cd ~/task-tracker/esphome
   esphome clean button-KIDNAME-TASK.yaml
   esphome run button-KIDNAME-TASK.yaml --device /dev/cu.usbmodem*
   ```
6. Watch the logs — you should see:
   - WiFi connected
   - API connected
   - Two clicks from the status LED toggling (boot feedback)
7. Disconnect USB-C

> If flashing fails: hold the BOOT button on the XIAO while connecting USB-C to force bootloader mode. Some USB-C cables are charge-only — use a data cable.

> **TEST**: After flashing, the onboard LED (GPIO15) should blink briefly on boot. If you hear two faint clicks from the board area, that's the boot success feedback — the buzzer will be louder once connected.

---

## Step 5 — Prep and solder the tact switch

The 6x6mm tact switch has 4 pins arranged in a square. Pins are connected in pairs — one pair per side.

1. Cut two lengths of 22 AWG wire, ~15cm each (one red, one black)
2. Strip 4mm from both ends of each wire
3. Tin the wire tips
4. Solder one wire to **any pin on one side** of the switch
5. Solder the other wire to **any pin on the opposite side**
6. Solder the **red wire** from the switch to the **D1** pin on the XIAO
7. Solder the **black wire** from the switch to any **GND** pin on the XIAO

> You can twist bare wire around the tact switch pins before soldering — this gives a stronger mechanical connection. Don't over-twist (2-3 wraps max).

> **TEST**: Power on the XIAO (USB or battery). Open ESPHome logs:
> ```
> esphome logs button-KIDNAME-TASK.yaml --device 192.168.x.x
> ```
> Press the switch — you should see `Binary sensor 'Task Button' changed to ON` in the logs. If the server is running, you'll also see the HTTP response.

---

## Step 6 — Prep and solder the buzzer

The passive buzzer has 2 pins. One may be marked `+` or have a longer lead.

1. Cut two short lengths of wire, ~10cm each
2. Tin the wire tips
3. Solder red wire to the `+` pin (or longer lead)
4. Solder black wire to the other pin

> **TEST the buzzer before soldering to the XIAO**: Touch the buzzer wires to a 3V3 source (the 3V3 pin on the XIAO while powered) and GND. You should hear a click when you touch and release. If no click, the buzzer is dead — swap it.

5. Solder **red wire** from buzzer to **D2** pin on the XIAO
6. Solder **black wire** from buzzer to any **GND** pin on the XIAO (can share the switch's GND pin)

> **TEST**: Power on the XIAO. On boot, you should hear two short clicks (the success feedback pattern). If the server is running, press the button — you'll hear the response pattern:
> - **Two clicks** = success ("ok")
> - **One long click** = already done today
> - **Three quick clicks** = outside window / error

---

## Step 7 — Visual inspection before enclosure

Before closing up:

- [ ] No solder bridges between adjacent pins
- [ ] Battery polarity correct (double-check)
- [ ] All joints look shiny and solid (no cold joints)
- [ ] No bare wire touching anything it shouldn't
- [ ] Clean flux residue with isopropyl + cotton swab
- [ ] Tug-test all solder joints — nothing should move

---

## Step 8 — Full integration test

With all components soldered and the XIAO powered:

1. Watch ESPHome logs on your laptop (via USB or OTA):
   ```
   esphome logs button-KIDNAME-TASK.yaml --device 192.168.x.x
   ```
2. **Boot test**: Power cycle the XIAO — should hear two clicks (success pattern)
3. **Button test**: Press the tact switch:
   - Logs should show: button press detected, HTTP POST sent, response received
   - Buzzer should click with the appropriate pattern
4. **Server response test** (if between 6-9:30 AM): Should get "ok" response and two clicks
5. **Voltage check**: Measure battery voltage across BAT+/BAT- — should be 3.5-4.2V

> If you see `outside_window` — that's correct, it just means it's not between 6-9:30 AM. Three clicks confirms the full chain is working.

---

## Step 9 — Assemble in enclosure

*(Do this after enclosure is 3D printed and tested mechanically)*

1. Place XIAO in its slot, USB-C port aligned with enclosure opening
2. Route battery alongside or below XIAO — keep wires away from the plunger path
3. Mount tact switch under the plunger post — confirm switch actuates at bottom of plunger travel
4. Mount buzzer against inside wall, sound hole aligned with enclosure grille
5. Close enclosure (screws or snap-fit depending on print design)
6. **Press the plunger** — confirm tact switch clicks at bottom of travel

---

## Step 10 — Label and mount

1. Apply kid sticker + task icon to plunger face
2. Test WiFi signal at intended mounting location (hold button there, check ESPHome logs)
3. Clean wall surface with isopropyl alcohol
4. Peel Command strip backing, press to back of enclosure
5. Press button to wall for 30 seconds
6. **Do one final press test from mounted position** — watch logs to confirm

---

## Per-Button Checklist

Run this for every button before calling it done.

```
Button: _______________________   Date: __________

[ ] Board inspected, no damage
[ ] Battery polarity verified with multimeter
[ ] Battery soldered to BAT+/BAT-
[ ] Charge LED lights when USB-C plugged in
[ ] Firmware flashed via USB-C
[ ] WiFi connects (check logs)
[ ] Tact switch soldered to D1 + GND
[ ] Button press appears in logs
[ ] Buzzer tested standalone (click on 3V3 touch)
[ ] Buzzer soldered to D2 + GND
[ ] Boot feedback: two clicks heard
[ ] Button press: buzzer clicks with response pattern
[ ] HTTP POST reaches server (check server logs)
[ ] All solder joints tug-tested
[ ] No solder bridges or stray wires
[ ] Enclosure assembled, plunger travel feels good
[ ] Sticker applied (correct kid + task)
[ ] Mounted at correct location and height
[ ] Final press test from wall
```

---

## Creating a New Button YAML

For each new button, create a file like `button-KIDNAME-TASK.yaml`:

```yaml
substitutions:
  device_name: button-KIDNAME-TASK
  owner: KIDNAME
  task: TASK
  pi_ip: !secret pi_ip

packages:
  common: !include .base-common.yaml
  button: !include .base-button.yaml
```

That's it. All the logic lives in `.base-button.yaml` and `.base-common.yaml`. The only things that change per button are `device_name`, `owner`, and `task`.

### secrets.yaml

Must contain (example values — use your own):

```yaml
wifi_ssid: "YourNetwork"
wifi_password: "YourPassword"
api_encryption_key: "base64-encoded-key"
ota_password: "your-ota-password"
pi_ip: "34.208.73.189"
```

---

## OTA Updates (after first flash)

Once a button is flashed and on WiFi, you can update it over the air:

```
esphome run button-KIDNAME-TASK.yaml --device 192.168.x.x
```

Find the device IP in your router's DHCP table or ESPHome logs.

---

## Build Order (recommended)

Build in this order. Test each one fully before moving on.

1. **Ryker — Teeth** *(bathroom, easy location, good first test)*
2. **Logan — Teeth** *(same room, do both while you have the iron hot)*
3. **Ryker — Plates**
4. **Logan — Plates**
5. **Ryker — Laundry**
6. **Logan — Laundry**
7. **Ryker — Pills**

---

## Troubleshooting

| Symptom | Likely cause | Fix |
|---|---|-----|
| XIAO won't boot | Bad battery joint / short | Check polarity, inspect solder |
| Won't connect to WiFi | Wrong SSID/password in secrets.yaml | Check `secrets.yaml` |
| Flash fails via USB | Bad USB cable (charge-only) | Try a different USB-C data cable |
| No HTTP POST in logs | Server not running | Start server, check `pi_ip` in secrets.yaml |
| Two clicks on press | Server returned "ok" | Working correctly |
| One long click on press | Task already done today | Expected — resets at 3 AM |
| Three clicks on press | Outside 6-9:30 AM window or error | Check time or server logs |
| No buzzer sound | Bad solder on D2 or GND | Reflow joints; test buzzer standalone with 3V3 |
| Button not detected | Cold joint on D1 or GND | Reflow D1/GND; check logs for binary_sensor |
| Boot hangs / crashes | Empty pi_ip or bad config | Verify secrets.yaml has all keys |
| `esphome run` uses cached build | Stale build cache | Run `esphome clean` first |

### Known platform limitations
- **LEDC/rtttl PWM does not work** on ESP32-C6 with esp-idf framework. Buzzer uses plain GPIO toggle (clicks, not tones). This is a known issue — do not attempt to use `platform: ledc` or `rtttl:` components.
- **Deep sleep** is currently disabled due to ESP-IDF 5.1.5 sleep crash. Will be re-enabled in a future firmware update.
- **GPIO3** is the RF switch power pin on the XIAO ESP32-C6. Never use it for user I/O.

---

## Display Build

See separate guide once enclosure design is finalized. The display (Waveshare 7.5" + ESP32 driver board) does not use battery power — it's wall-mounted with USB-C. Assembly is simpler: just mount panel to driver board and flash firmware.

---

*Last updated: 2026-03-11*

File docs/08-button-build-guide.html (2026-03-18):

# 🔧 Button Build Guide

AM Routine Tracker — Avalon Household | Print this. Build one button at a time. Don't skip steps.

## Before You Start

### Tools needed

- Soldering iron + solder
- Wire strippers
- Multimeter
- Heat gun (or lighter) for heat shrink
- USB-C cable (for flashing)
- Laptop with ESPHome dashboard open
- Tweezers & isopropyl alcohol + cotton swab

### Parts per button unit

Part | Notes
1× Seeed XIAO ESP32-C6 | The brains
1× 3.7V 400mAh LiPo (Liter 502035) | 5×20×35mm
1× 6×6×5mm tactile pushbutton switch | 4-pin through-hole, momentary
1× Passive piezo buzzer (~12mm, 2-pin) | Passive, NOT active
~15cm red + black 22 AWG silicone wire | For tact switch
~10cm red + black 22 AWG silicone wire | For buzzer
2× small heat shrink pieces | Battery solder joints
1× 3D-printed enclosure + plunger | Print before assembly

## GPIO Pin Assignments — Memorize These

Function | XIAO Pin Label | GPIO #
Tact switch input | D1 | GPIO1
Passive buzzer PWM | D2 | GPIO2
Battery positive | BAT+ pad | near D5 silkscreen (back of board)
Battery negative | BAT- pad | near D8 silkscreen (back of board)

⚠️ GPIO3 is NOT D1. GPIO3 is the RF switch power pin — an internal board signal. Do not use it. The correct mapping is D1 = GPIO1, D2 = GPIO2. The full XIAO pin map: D0=GPIO0, D1=GPIO1, D2=GPIO2, D3=GPIO21, D4=GPIO22, D5=GPIO23.

## 1 Inspect the XIAO board

- ☐ No bent pins, no visible damage
- ☐ USB-C port is clean
- ☐ Find the BAT+ pad on back of board (near D5 label)
- ☐ Find the BAT- pad on back of board (near D8 label)

## 2 Prep the LiPo battery

⚠️ LiPo batteries can catch fire if shorted. The two bare wire ends must never touch each other — insulate them immediately after cutting.

1. Cut off the JST connector leaving ~5cm of wire attached to the battery
2. Immediately slide a piece of heat shrink over each wire end and shrink it down — leave only ~4mm of wire exposed at the tip. Do this before anything else. Both ends insulated before you proceed.
3. Strip the 4mm tips
4. Tin both wire tips with solder

## 3 Solder battery to XIAO

1. Tin the BAT+ and BAT- pads on the back of the XIAO
2. Verify polarity with multimeter before soldering (red = +, black = −, but verify — some units are reversed)
3. Solder red wire to BAT+ pad
4. Solder black wire to BAT- pad
5. Check that no wire strands are poking sideways toward adjacent pads
6. Tug gently — joints should not move

Note: no heat shrink needed on the board side — the solder pad is the joint. The heat shrink from Step 2 protects the battery-end wires from shorting against each other.

✅ Check: Plug in USB-C. Orange charge LED on XIAO should light up.

## 4 Prep the tact switch

1. Cut two ~2.5" wires (red + black)
2. Solder red wire to any pin on one side of the switch
3. Solder black wire to any pin on the opposite side
4. (The 4 pins are connected in pairs — you're bridging across the switch)

## 5 Solder switch to XIAO

1. Solder red wire → D1 pin on XIAO
2. Solder black wire → any GND pin on XIAO

✅ Check (optional — skip if you don't have alligator clip leads): The GDT-311 has no continuity beeper — use Ω mode, 200 range instead. Red probe to D1 wire, black probe to GND wire. Unpressed = "1." (open circuit). Pressed = near 0. You need both hands to hold probes + one to press — use alligator clip leads or a helping-hands stand, or just skip and verify during the firmware test in Step 10.

## 6 Prep the buzzer

1. Cut two ~2.5" wires
2. Solder one wire to one pin, other wire to the other pin — polarity doesn't matter for a passive buzzer, it's driven by PWM not DC

## 7 Solder buzzer to XIAO

1. Solder red wire → D2 pin on XIAO
2. Solder black wire → any GND pin on XIAO

## 8 Visual inspection before flashing

- ☐ No solder bridges between adjacent pins
- ☐ Battery polarity correct (double-check)
- ☐ All joints shiny and solid
- ☐ No bare wire touching anything it shouldn't
- ☐ Clean flux residue with isopropyl + cotton swab

## 8b Pre-flash electrical test (do this before touching a computer)

Set multimeter to Ω mode, 200 range. The GDT-311 has no beeper — watch the display.

1. Test each solder joint: probe the wire above the joint on one side, probe the board pad on the other. Should read near 0. If it reads OL or high, reflow the joint.
2. Test switch continuity: probe the two button wires (at any exposed metal — connector pins, stripped sections). Unpressed = OL or ~2.0. Pressed = near 0. If it reads near 0 unpressed, the switch is shorted — replace it.
3. Test no shorts: probe D1 pad to D2 pad. Should read OL. Probe any signal pad to GND unpressed. Should read OL (D1) or near 0 (GND-to-GND).

If you can't hold probes + press the switch at the same time, skip the switch continuity test here and verify it in Step 10 via the logs instead.

## 9 Flash ESPHome firmware

1. Open ESPHome dashboard on your laptop
2. Copy the correct YAML from repo — e.g. button-ryker-laundry.yaml
3. Confirm secrets.yaml has WiFi credentials and API key filled in
4. Click Install → Plug into this computer
5. Connect XIAO via USB-C
6. Wait for compile + flash (~2–3 min)
7. Watch logs for: WiFi connected → API connected → Button handler registered
8. Disconnect USB-C

If flash fails: hold BOOT button on XIAO while connecting USB-C to force bootloader mode.

## 10 First press test (before enclosure)

1. Flash the device and open logs
2. Confirm GPIO1 is reading correctly: with logs streaming, briefly short the D1 and GND wires together. You should see Button pressed in the logs. If not — stop here and troubleshoot before proceeding.
3. Press the physical tact switch
4. Confirm in logs: Button pressed → HTTP POST sent → response received
5. Buzzer should beep on press
6. XIAO returns to deep sleep within 10 seconds

{"status": "outside_window"} = working fine, just not during the task window
{"status": "already_done"} = working fine, task already logged today

If shorting D1+GND works but physical switch press doesn't: the solder joint on the switch is the problem. Reflow both switch joints and retest.

## 11 Assemble in enclosure

(After 3D print is ready and mechanically tested)

1. Place XIAO in slot with USB-C aligned to enclosure opening
2. Route battery alongside/below XIAO
3. Mount tact switch under plunger post — confirm it actuates at bottom of plunger travel
4. Mount buzzer against inside wall, aligned with sound grille
5. Close enclosure
6. Press plunger — confirm tact switch clicks at bottom of travel

## 12 Label and mount

1. Apply kid sticker + task icon to plunger face
2. Test WiFi signal at mounting location (hold button there, watch logs)
3. Clean wall surface with isopropyl alcohol, let dry
4. Peel Command strip backing, press to back of enclosure
5. Press button to wall for 30 seconds
6. Do one final press test from mounted position

## ✅ Per-Button Commissioning Checklist

Button: __________________________ Date: __________________

☐ Board inspected, no damage
☐ Battery polarity verified with multimeter
☐ Battery soldered to BAT+/BAT-
☐ Battery solder joints heat-shrunk
☐ Tact switch soldered to D1 + GND
☐ Buzzer soldered to D2 + GND
☐ Continuity check passed (D1–GND with switch press)
☐ ESPHome firmware flashed successfully
☐ WiFi connects in logs
☐ Button press event reaches Pi server (HTTP 200)
☐ LED flashes green on success
☐ Buzzer beeps on success
☐ XIAO enters deep sleep after press
☐ Enclosure assembled, plunger travel feels right
☐ Sticker applied (correct kid + task)
☐ Mounted at correct location and height (~36–42" from floor)
☐ Final press test from wall — event confirmed in logs

## Recommended Build Order

1. Ryker — Teeth (bathroom, good first test)

2. Logan — Teeth (same room)

3. Ryker — Plates

4. Logan — Plates

5. Ryker — Laundry

6. Logan — Laundry

7. Ryker — Pills

## Troubleshooting

Symptom | Likely cause | Fix
XIAO won't boot | Bad battery joint / short | Check polarity, inspect solder
Won't connect to WiFi | Wrong SSID/password in secrets.yaml | Reflash with corrected secrets
Flash fails | Not in bootloader mode | Hold BOOT + connect USB
No HTTP POST in logs | Pi server not running / wrong IP | Start Pi server, check IP in config
LED flashes red | Task already done today | Expected behavior — press tomorrow
No buzzer sound | Wrong pin / active buzzer used | Confirm D2, confirm passive buzzer
Switch not detected | Cold solder joint | Short D1+GND wires to test GPIO — if that works, reflow switch joints
GPIO never changes no matter what | Wrong GPIO in firmware (old configs used GPIO3 which is an internal RF switch pin) | Confirm firmware uses GPIO1 for D1 and GPIO2 for D2 — not GPIO3/GPIO4
Button presses ignored | Outside 6–9:30 AM window | Expected — or check server time

AM Routine Tracker — Avalon Household | Last updated 2026-03-06 | Questions → ask Iji

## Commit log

2026-03-05 feat: complete task tracker system - server, ESPHome configs, EC2 relay, deployment guide
2026-03-05 fix: 11 bugs from claude code review
    - Fix duplicate YAML keys in .base-button.yaml that silently killed all button functionality
    - Fix GPIO pin mismatch (GPIO9 -> GPIO3 for external tact switch, add GPIO4 buzzer)
    - Fix broken !secret inside quoted string for pi_ip resolution
    - Fix do_press lambda calling scripts as lights (turn_on -> execute)
    - Fix signal_relay.py default path from macOS Homebrew to Linux
    - Fix .base-display.yaml HomeAssistant dependency (-> SNTP)
    - Fix 5s e-ink polling interval (-> 60s, panel needs ~15s refresh)
    - Add threading.Lock for shared state in server.py
    - Add pi_ip substitution to all 9 button device YAMLs
    - Remove redundant deep_sleep run_duration
    Co-Authored-By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
2026-03-06 fix: base-button YAML - correct GPIO, deduplicate blocks, fix buzzer feedback
2026-03-06 fix: correct XIAO ESP32-C6 GPIO pin mapping
    - D1 = GPIO1 (was incorrectly GPIO3)
    - D2 = GPIO2 (was incorrectly GPIO4)
    - Deep sleep wakeup pin: GPIO1 (was GPIO3)
    - GPIO3 is the RF switch power pin, not a user GPIO
    - Board: esp32-c6-devkitc-1 + esp-idf (seeed_xiao_esp32c6 unsupported)
    Discovered during button-ryker-teeth build session 2026-03-06.
    Also update build guide with GPIO warning, pre-flash continuity test,
    wire-shorting firmware test, and expanded troubleshooting.
2026-03-06 fix: remove WS2812 RGB LED block — not present on XIAO ESP32-C6, neopixelbus incompatible with esp-idf
    Removed RGB LED configuration from the button YAML.
2026-03-06 fix: remove wakeup_pin from deep_sleep — GPIO1 conflict with binary_sensor
2026-03-06 Refactor comments and formatting in .base-button.yaml
    Updated comments for clarity and adjusted formatting in the YAML configuration.
2026-03-06 Refactor response handling in .base-button.yaml
2026-03-06 fix: disable deep_sleep to keep button alive for debugging
2026-03-06 wip: buzzer debugging — GPIO2 test mode, rtttl temporarily removed
    Testing GPIO2 output with simple switch to diagnose buzzer hardware.
    Feedback scripts replaced with logger placeholders until buzzer is fixed.
2026-03-08 fix: use GPIO toggle for buzzer instead of LEDC/rtttl
    LEDC PWM output does not work on ESP32-C6 with esp-idf framework.
    Switched to plain GPIO on/off toggling which produces audible clicks
    on the passive piezo buzzer. Different click patterns for each response:
    - success: 2 clicks
    - already_done: 1 long click
    - outside_window: 3 clicks
2026-03-08 docs: update build guide and design spec with lessons from first button build
    - Fix GPIO numbers: D1=GPIO1, D2=GPIO2 (not GPIO3/GPIO4)
    - Document LEDC/rtttl limitation on ESP32-C6 with esp-idf
    - Reorder build steps: flash firmware before soldering switch/buzzer
    - Add test-as-you-go checkpoints after each soldering step
    - Add new button YAML template and OTA update instructions
    - Update troubleshooting with real issues encountered
    - Add .gitignore for flash/test yamls containing credentials
    - Resolve GPIO pin assignment in design spec open questions
2026-03-18 Resolve merge conflicts and sync local changes
    Merge stashed local work (EC2 migration, server updates, display/button
    config changes, 3D enclosure files) with upstream build guide updates.
    [battery-clip.stl, button-enclosure-pillar-test.stl, button-enclosure-rectangle-piller-test.stl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]
